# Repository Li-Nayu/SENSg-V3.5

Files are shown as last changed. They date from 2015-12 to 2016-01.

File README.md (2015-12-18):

SENSg-V3.5
==========
<h4>National Science Experiment: SENsg,  Large-scale Internet of Things Sensor Deployment in SUTD, Singapore</h4>

#Overview
V3.5 of SENSg is developed during my exchange period in SUTD, Singapore. Thanks to Professor Wilhelm Erik's kind guidance.

#Change Log
* Add P-channel MOSFET as the power switch for camera. MOSFET is controlled by MCU pin1, which is also the LDR sensor's GPIO pin. 
* With a pull-up resistor, the camera won't on unless the pin1 gives a low voltage. Also the camera's VCC input is changed to MOSFET's source.
* All changes were tested.

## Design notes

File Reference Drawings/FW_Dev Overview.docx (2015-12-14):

# SENSg Firmware Development Overview

# 1. V4

## 1.1. HW

What | Where | Link
Schematics | Google SENSg Drive | https://drive.google.com/drive/folders/0B7DpkhRStnrifm95Z2t1MTVseUd5ZGhOa0FhOWctQkhuNlJZZ3pQanJJbHhZMnU5bmlOZEk
Datasheets | Git SENSgV4 | https://github.com/SUTDMEC/SENSgV4/tree/master/datasheets

## 1.2. SW

What | Where | Link
Firmware Repository | Git SENSgV4 | https://github.com/SUTDMEC/SENSgV4
Development Setup | Git SENSgV4 | https://github.com/SUTDMEC/SENSgV4/wiki
Documentation | Git SENSgV4 | https://github.com/SUTDMEC/SENSgV4/tree/master/documents
Documentation | Google SENSg Drive | https://drive.google.com/drive/folders/0B7DpkhRStnrifmJVV1dtaHV1aF85Tnh1ckhTOUxUanZnam4zbUtBdXp3aHRtV045ZDlzZWM
Test Plans | Google SENSg Drive | https://drive.google.com/drive/folders/0B7DpkhRStnrifnhCbGhJeDdnWGVrSzdkeTBONUJSbk45VVZRVzVYc2ZOX3dZOHlpS0NJYTQ
To Do List | Google SENSg Drive | https://docs.google.com/spreadsheets/d/1tqt-cK1kPYpz1u6wyrGCkvDzCyMbWx9modV9bSj_76Y
Open Issues | Git SENSgV4 | https://github.com/SUTDMEC/SENSgV4/issues

# 2. V3

## 1.3. HW

What | Where | Link
Schematics
Datasheets | Git SenseSing | https://github.com/SUTDMEC/SenseSing/tree/master/V3%20-%20BM-09%20Based/Datasheets

## 1.4. SW

What | Where | Link
Firmware Repository | Git sensg-private | https://github.com/SUTDMEC/sensg-private
Development Setup | Git SenseSing | https://github.com/SUTDMEC/SenseSing/wiki
Development Setup | Google SENSg Drive | https://drive.google.com/drive/folders/0B7DpkhRStnrifmJVV1dtaHV1aF85Tnh1ckhTOUxUanZnam4zbUtBdXp3aHRtV045ZDlzZWM

Firmware Development Overview

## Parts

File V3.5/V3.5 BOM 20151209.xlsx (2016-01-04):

Sub-System | Description & Link | Category | Supplier | DELTA Sourcing | Package / Case | Supplier | Supplier Part # | Units /Piece | Reference on the PCB
Power & Charging | 1800 mAh Li-Po Battery (http://www.alibaba.com/product-detail/3-7v-1800mah-flat-li-ion_701608271.html) | Battery |  | V |  | Data Power |  | 1 |  | USD Conv.
 | 3.3v DC/DC converter (http://www.digikey.sg/product-search/en?x=0&y=0&KeyWords=RT8008-33GB) | IC | Richtek | V | SOT-23 | Digikey | RT8008-33GB-ND | 1 | U3
 | MCP73831T (Charging) (http://sg.element14.com/jsp/search/productdetail.jsp?id=1332158) | IC | Microchip | FIX | SOT-5 | Element14 | 1332158 | 1 | U2
 | MICRO USB (http://sg.element14.com/molex/47346-0001/micro-usb-2-0-type-b-receptacle/dp/1568026) | Connector | MOLEX | V |  | Element14 | 1568026 | 1 | JP1
 | 4.7 uF (http://sg.element14.com/murata/grm155r60j475me47d/cap-mlcc-x5r-4-7uf-6-3v-0402/dp/2426952) | MLCC | Murata | V | 402 | Element14 | 2426952 | 2 | C7,C10
 | 2K OHM (http://sg.element14.com/vishay-draloric/crcw06032k00fkea/product-range-vishay-crcw-series/dp/1469764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) | Resistor | Murata | V | 603 | Element14 | 1469764 | 1 | R1
 | 100 OHM (http://sg.element14.com/yageo-phycomp/rc0603jr-07100rl/resistor-rc21-0603-100r/dp/9233253) | Resistor | Yageo | V | 603 | Element14 | 9233253 | 1 | R3
 | Indicator LED SMT (http://sg.element14.com/kingbright/ka-2810asursk/led-smd-2-8-x-0-8mm-side-view-red/dp/2146470) | LED | Everlight | V | RA_SMD_LED | Element14 | 2146470 | 1 | LED
 | 0.1 uF (0402) (http://sg.element14.com/multicomp/mc0402x104k100ct/cap-mlcc-x5r-100nf-10v-0402/dp/1759380RL) | MLCC | MLCC | V | 402 | Element14 | 1759380RL | 1 | C12
 | 22uf (http://sg.element14.com/tdk/c1608x5r0g226m080aa/ceramic-capacitor-22uf-4v-x5r/dp/2354098) | MLCC |  | V | 603 | Element14 | 2354098 | 2 | C8,C11
 | 100K 1% (http://sg.element14.com/multicomp/mcsr04x1003ftl/resistor-0402-100k-1-anti-sulfur/dp/2073962) | Resistor | Multicomp | V | 402 | Element14 | 2073962 | 1 | R2
 | JST Header 2-way SMT (http://sg.element14.com/jst-japan-solderless-terminals/s2b-ph-sm4-tb-lf-sn/connector-header-smt-r-a-2mm-2way/dp/9492615) | Connector | JST | V |  | Element14 | 9492615 | 1 | BAT
 | Inductor 2.2 uH (http://www.mouser.sg/ProductDetail/Taiyo-Yuden/NR3015T2R2M/?qs=PzICbMaShUc5oMpwvLtSLA%3D%3D) | Inductor | Taiyo Yuden (http://www.mouser.sg/Taiyo-Yuden/) | V | INDUCTOR-NR3015 | Mouser | 963-NR3015T2R2M | 1 | L2
Main PCB components | BM-09 (http://www.usish.com/pdf/EN_flyer.pdf) | MCU+WIFI | USI | FIX |  | EDOM/USI |  | 1 | U1 | USD Conv.
 | 0.1 uF (0402) (http://sg.element14.com/multicomp/mc0402x104k100ct/cap-mlcc-x5r-100nf-10v-0402/dp/1759380RL) | MLCC | MLCC | V | 402 | Element14 | 1759380RL | 4 | C2,C4,c6,C22
 | 10 uF (0402) (http://sg.element14.com/tdk/c1005x5r0j106m050bc/cap-mlcc-x5r-10uf-6-3v-0402/dp/2346872) | MLCC | MLCC | V | 402 | Element14 | 2346872 | 3 | C1,C3,C5
 | 10K OHM 1% (http://sg.element14.com/multicomp/mcsr04x1002ftl/resistor-0402-10k-1-anti-sulfur/dp/2073960) | Resistor | Multicomp | V | 402 | Element14 | 2073960 | 1 | R13
 | SMD Tactice Button (http://sg.element14.com/te-connectivity-alcoswitch/fsm4jsmatr/switch-tactile-spst-50ma-smd-outside/dp/2410652) | Switch | Tyco | V | TACTILE_SWITCH_SMD_LARGE_4 | Element14 | 2410652 | 2 | S1,S2
 | Reset Switch (http://sg.element14.com/webapp/wcs/stores/servlet/ProductDisplay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) | Switch | Multicomp | V | DTSM-3 | Element14 | 9471898 | 2 | S3,S4
 | Switch (http://sg.element14.com/eao/09-10290-01/switch-slide-spdt-co-500ma-thd/dp/674357) | Switch | EAO | V |  | Element14 | 1634623 | 1 | SW
 | 4.7K OHM 1% (http://sg.element14.com/multicomp/mc00625w040214k7/resistor-4k7-0-063w-1-0402/dp/1358060) | Resistor | Multicom | V | 402 | Element14 | 1358060 | 2 | R6,R7
 | RGB LED (http://sg.element14.com/cree/clv1l-fkb-chmmqehbb7673673/led-red-green-blue-plcc-4/dp/2414451?ost=2414451) | LED | CREE | V |  | Element14 | 2414451 | 1 | RGB_LED
 | Chip Antenna (http://www.digikey.sg/product-detail/en/2450AT43B100E/712-1010-2-ND/1560681) | RF Antenna | Johanson | FIX |  | Digikey | 712-1010-2-ND | 1 | ANT1
 | 0.8pF RF CAP (http://www.digikey.sg/product-detail/en/GJM1555C1HR80BB01D/490-6080-2-ND/2593264) | MLCC | Murata | V | 0402_B | Digikey | 490-6080-2-ND | 1 | C9
 | 3.3nH RF IND (http://www.hksunlord.com/Multilayer_Inductor.php?page=7) | Inductor | TBA | V | 0402_B | MFG: Hong Kong SUNLORD Co.,Ltd. | PN: HCI1005F-3N3J | 1 | L1
 | 1K OHM (http://sg.element14.com/multicomp/mc00625w040211k/resistor-1k-0-063w-1-0402-reel/dp/2130354) | Resistor | Multicomp | V | 402 | Element14 | 2130354 | 3 | R9,10,R11
 | 22 ohm (http://sg.element14.com/multicomp/mc00625w0402122r/resistor-22r-0-063w-1-0402/dp/1357998) | Resistor | Multicomp | V | 402 | Element14 | 1357998 | 2 | R4,R5
SD | Micro SD Card Slot (http://sg.element14.com/global-connector-technology/mem2051-00-195-00-a/connector-memory-card-micro-sd/dp/2143377) |  | TBA | V |  |  |  | 1 | U8
 | Micro SD Card 8GB (http://www.alibaba.com/product-detail/8GB-micro-SD-card-Class10-TF_1877618164.html) | IC | TBA | FIX |  | Alibaba |  | 1
IMU | MPU 9150 (http://www.invensense.com/mems/gyro/documents/PS-MPU-9150A-00v4_3.pdf) | MCU |  | FIX |  | Digikey (http://www.digikey.com/product-detail/en/MPU-9150/1428-1009-2-ND/4038013) | 1428-1009-2-ND | 1 | U4
 | 0.1 uF (0402) (http://sg.element14.com/multicomp/mc0402x104k100ct/cap-mlcc-x5r-100nf-10v-0402/dp/1759380RL) | MLCC | Multicomp | V | 402 | Element14 | 1759380RL | 2 | C13,C17
 | 10nF (0.01uF) (http://in.element14.com/tdk/c1005x7r1e103k050bb/capacitor-ceramic-0-01uf-25v-x7r/dp/1844133) | MLCC |  | V | 402 | Element14 | 1844133 | 1 | C18
 | 2.2nF (2200pF) (http://sg.element14.com/murata/grm155r71h222ka01d/cap-mlcc-x7r-2-2nf-50v-0402/dp/1828884) | MLCC | Murata | V | 402 | Element14 | 1828884 | 1 | C14
LDR | LDR (http://sg.element14.com/excelitas-tech/vt90n1/ldr-200kohm-80mw-vt900-series/dp/2568243) | Photoconductive Cell | EXCELITAS TECH | FIX |  | Digikey |  | 1 | KDR
 | 1.2K OHM 1% (http://sg.element14.com/multicomp/mc0063w060311k2/res-thick-film-1k2-1-0-063w-0603/dp/9330500?ost=9330500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) | Resistor | MULTICOMP | V | 603 | Element14 | 9330500 | 1 | R12
 | 2K OHM 1% (http://sg.element14.com/multicomp/mc0063w060312k/res-thick-film-2k-1-0-063w-0603/dp/9330763?ost=9330763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) | Resistor | MULTICOMP | V | 603 | Element14 | 9330763 | 1 | R20
Mic | Mic (http://sg.element14.com/projects-unlimited/aom-4542p-r/microphone-omni-pcb-9-7mm/dp/1193029) | IC | PROJECTS UNLIMITED (http://sg.element14.com/projects-unlimited) | FIX | OFN-24Np | Element14 | 1193029 | 1 | U9
 | OPA344 Opamp (http://sg.element14.com/texas-instruments/opa344na-250/ic-op-amp-1mhz-0-8v-us-sot-23-5/dp/9547550) | IC | TI | FIX | SOT-23-5 | Element14 | 9547550 | 1 | U10
 | 10K OHM 1% (http://sg.element14.com/multicomp/mcsr04x1002ftl/resistor-0402-10k-1-anti-sulfur/dp/2073960) | Resistor | Multicomp | V | 402 | Element14 | 2073960 | 3 | R15,16,R17
 | 1M 1% (http://sg.element14.com/panasonic/erj-2rkf1004x/resistor-thick-film-1mohm-100mw/dp/2284171) | Resistor | Panasonic | V | 402 | Element14 | 2284171 | 1 | R18
 | 12pF (http://sg.element14.com/murata/grm1555c1h120ja01d/cap-mlcc-c0g-np0-12pf-50v-0402/dp/1828875) | MLCC | Murata | V | 402 | Element14 | 1828875 | 1 | C25
 | 2.2 K ohm (http://sg.element14.com/panasonic-electronic-components/erj2rkf2201x/res-thick-film-2k2-100mw-1-0402/dp/2302673) | Resistor | Panasonic | V | 402 | Element14 | 2302673 | 1 | R14
 | 4.7 uF (http://sg.element14.com/murata/grm155r60j475me47d/cap-mlcc-x5r-4-7uf-6-3v-0402/dp/2426952) | MLCC | Murata | V | 402 | Element14 | 2426952 | 1 | C23
 | 1.0 uF (http://sg.element14.com/tdk/c1005x5r0j105k050bb/ceramic-capacitor-1uf-6-3v-x5r/dp/2371907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) | MLCC | C5 | V | 402 | Element14 | 1844105 | 1 | C24
 | 0.1 uF (0402) (http://sg.element14.com/multicomp/mc0402x104k100ct/cap-mlcc-x5r-100nf-10v-0402/dp/1759380RL) | MLCC | Multicomp | V | 402 | Element14 | 1759380RL | 1 | $26.000
Humidity & Temperature | HTU21D (http://sg.element14.com/measurement-specialties/htu21d/humidity-digital-3-rh-dfn-6/dp/2393536?Ntt=HTU21D) | IC | Measurement | FIX |  |  |  | 1 | U5
 | 0.1 uF (0402) (http://sg.element14.com/multicomp/mc0402x104k100ct/cap-mlcc-x5r-100nf-10v-0402/dp/1759380RL) | MLCC | Multicomp | V | 402 | Element14 | 1759380RL | 1 | C15
Barometer | BMP180 (http://www.mouser.sg/ProductDetail/Bosch-Sensortec/BMP180/?qs=sGAEpiMZZMsrChSOYEGTCcbpL13VfRyojs5HQb1tBiU%3d) | IC | Bosch | FIX |  |  | 262-BMP180 | 1 | U7
 | 10uF Tant (http://sg.element14.com/jsp/search/productdetail.jsp?sku=2333009) | CAP | AVX | V | 1206 | Element14 | 2333009 | 1 | C19
 | 0.1 uF (0402) (http://sg.element14.com/multicomp/mc0402x104k100ct/cap-mlcc-x5r-100nf-10v-0402/dp/1759380RL) | MLCC | Multicomp | V | 402 | Element14 | 1759380RL | 2 | C20,C21
IR Temperature | TMP007 (http://www.digikey.sg/product-detail/en/TMP007AIYZFT/296-37914-1-ND/4900960) | IC | TI | FIX |  | Digikey | 296-28819-2-ND | 1 | U6
 | 10K OHM 1% (http://sg.element14.com/jsp/search/productdetail.jsp?sku=1469748RL) | Resistor | Vishay | V | 603 | Element14 | 1469748RL | 1 | R8
 | 0.1 uF (0402) (http://sg.element14.com/multicomp/mc0402x104k100ct/cap-mlcc-x5r-100nf-10v-0402/dp/1759380RL) | MLCC | MLCC | V | 402 | Element14 | 1759380RL | 1 | C16
Buzzer | ID 1740 Buzzer (http://www.adafruit.com/product/1740) | Buzzer | Adafruit | V |  | Adafruit | 1740 | 1 | BUZZ | USD Conv.
Camera | C1098 (http://www.comedia.com.hk/) | Camera | 康大 | V |  | COMedia |  | 1 | CAM | JPEG serial camera. Minimum VGA quality.
 | P-CHANNEL MOSFET (http://sg.element14.com/fairchild-semiconductor/nds356ap/mosfet-p-sot-23/dp/9846409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) | MOSFET | Fairchild Semiconductor | V | SOT-23 | Element14 | 9846409 | 1 | Q1
 | Header (http://sg.element14.com/molex/22-03-2041/header-square-pin-0-1-4way/dp/9731091) | Connector | Molex | V |  | element14 | 9731091 | 1
Additional components | Case (thermoplastic injection molded) |  |  |  |  |  |  | 1
Programming Board | JTAG header (http://sg.element14.com/fci/20021111-00008t4lf/header-vert-1-27mm-tht-8way/dp/1865284) | Connector | FCI | v |  | Element14 | 1865284 | 1 | Jtag

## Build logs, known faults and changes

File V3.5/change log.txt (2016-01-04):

Schematic:
1.Changed to Micro USB B.lbr
2.Changed the position of LDR and R12£¬add pull-up resistor R20.

pin1 voltage: [R12 & R20 are tested]
condition                       value
total darkness               around 3.0V
normal condition          2.5V
with phone's flashlight around  2.0V
MOSFET S output
in any condition above 
<=0.3V

3.Add P-channel Mosfet
4.Changed Camera's 3.3V port, named it MOSFET_CONTROL

ERC & DRC check

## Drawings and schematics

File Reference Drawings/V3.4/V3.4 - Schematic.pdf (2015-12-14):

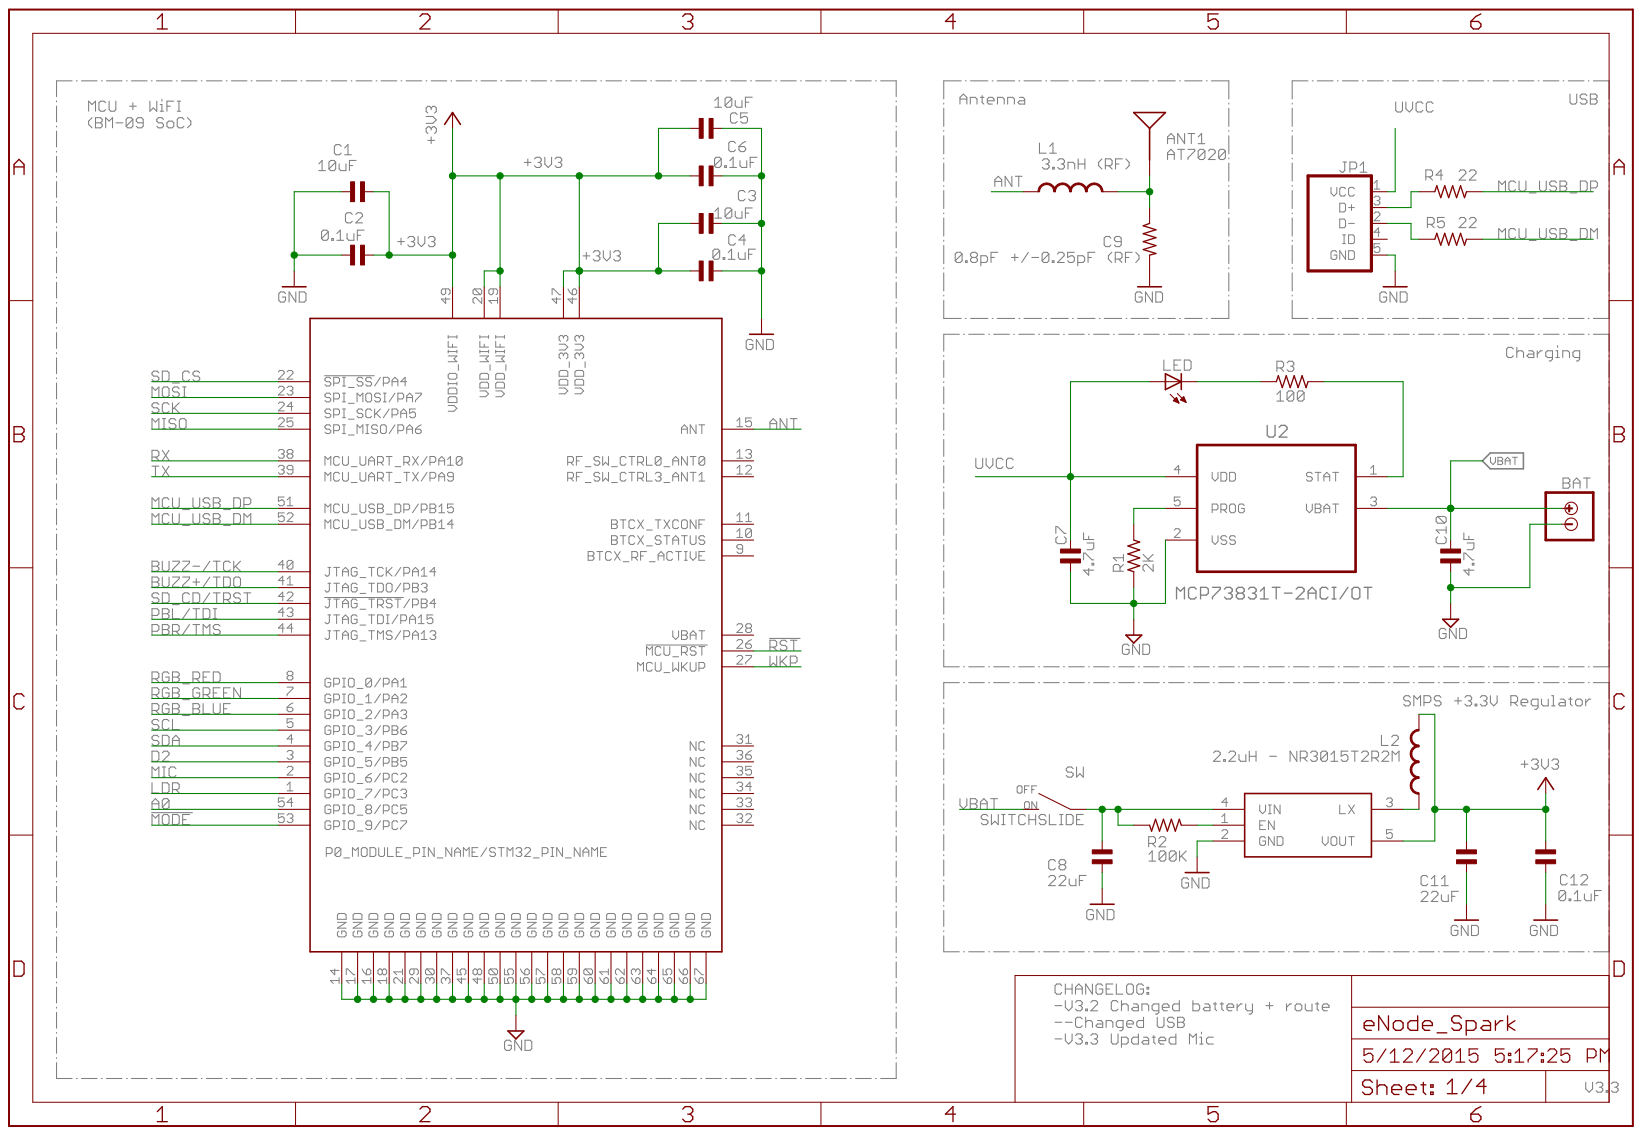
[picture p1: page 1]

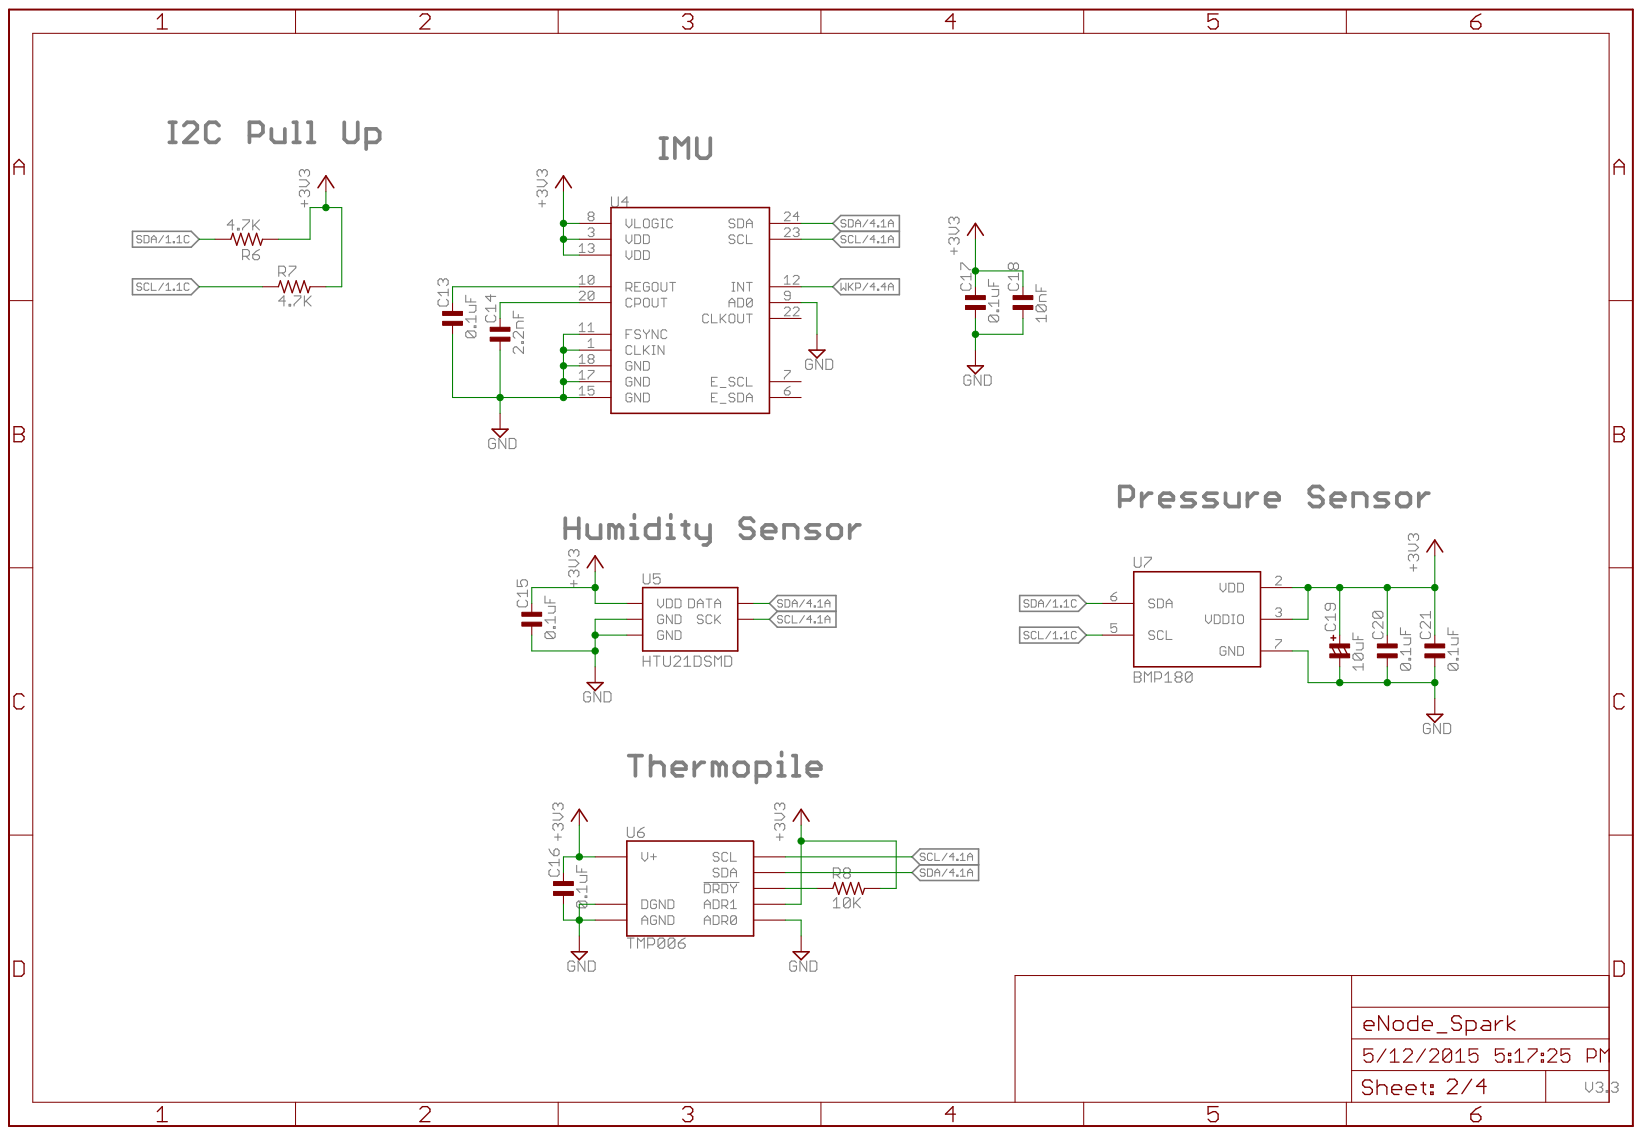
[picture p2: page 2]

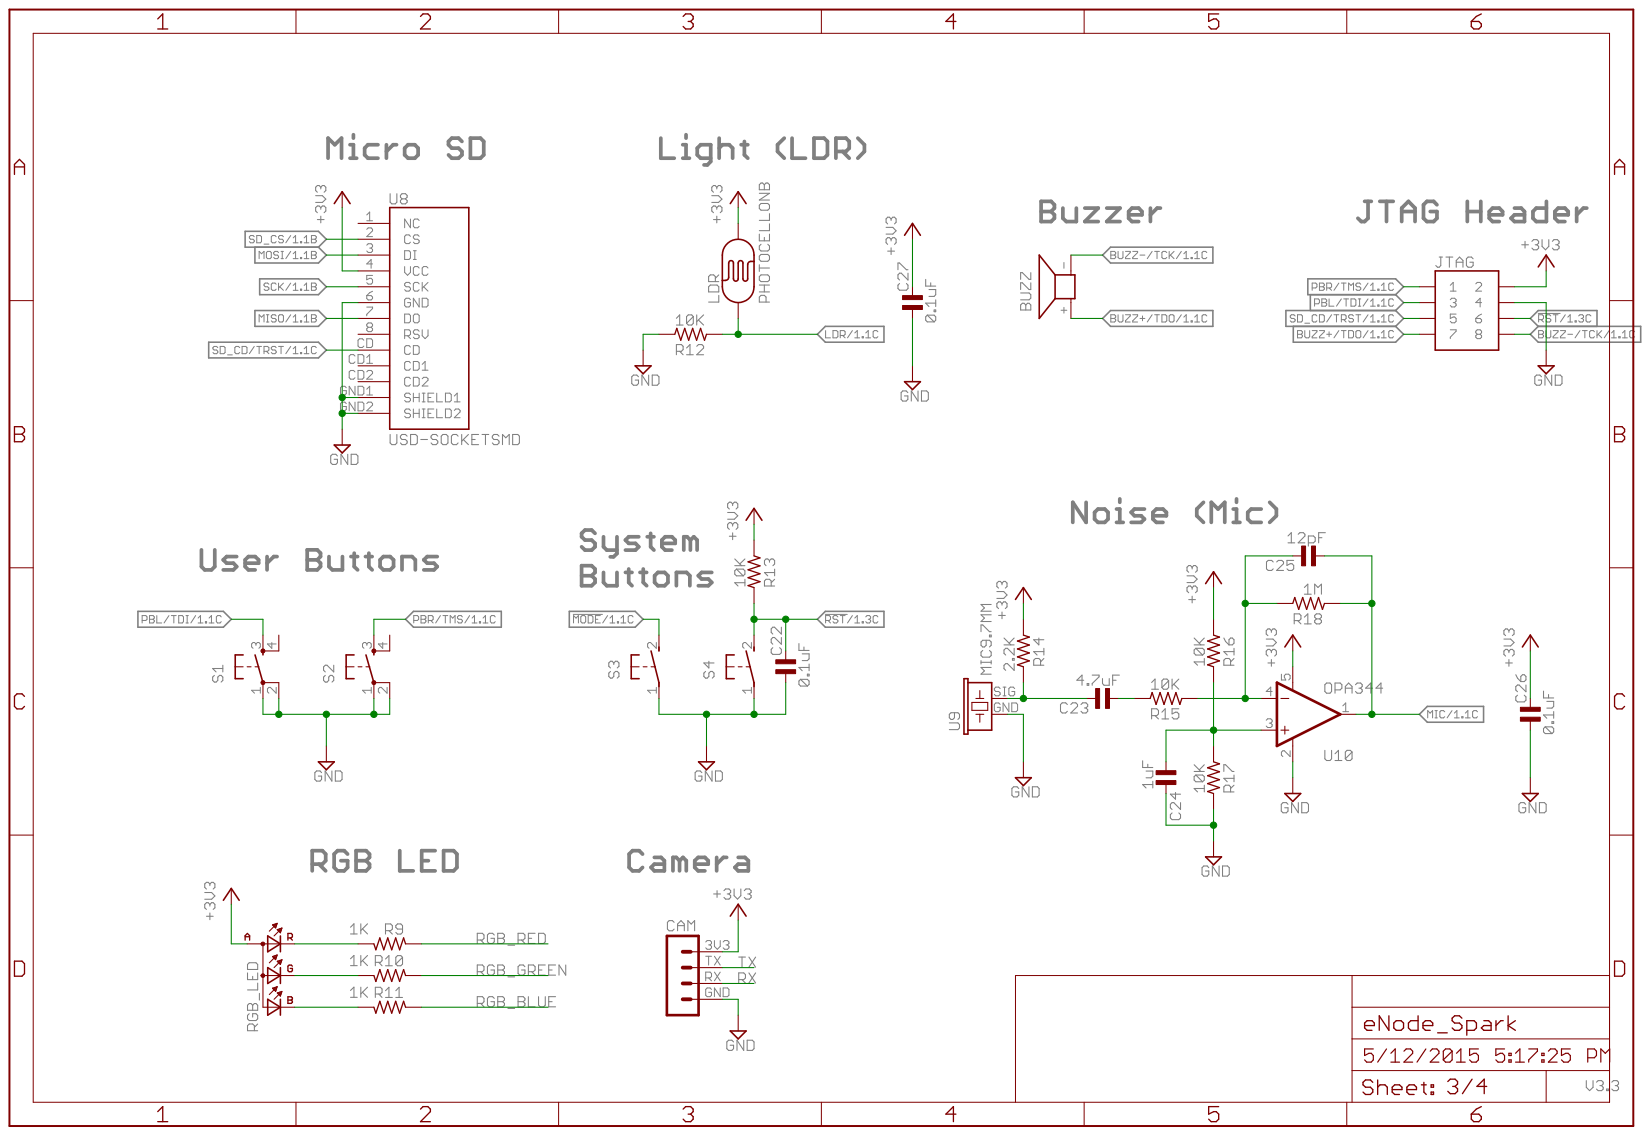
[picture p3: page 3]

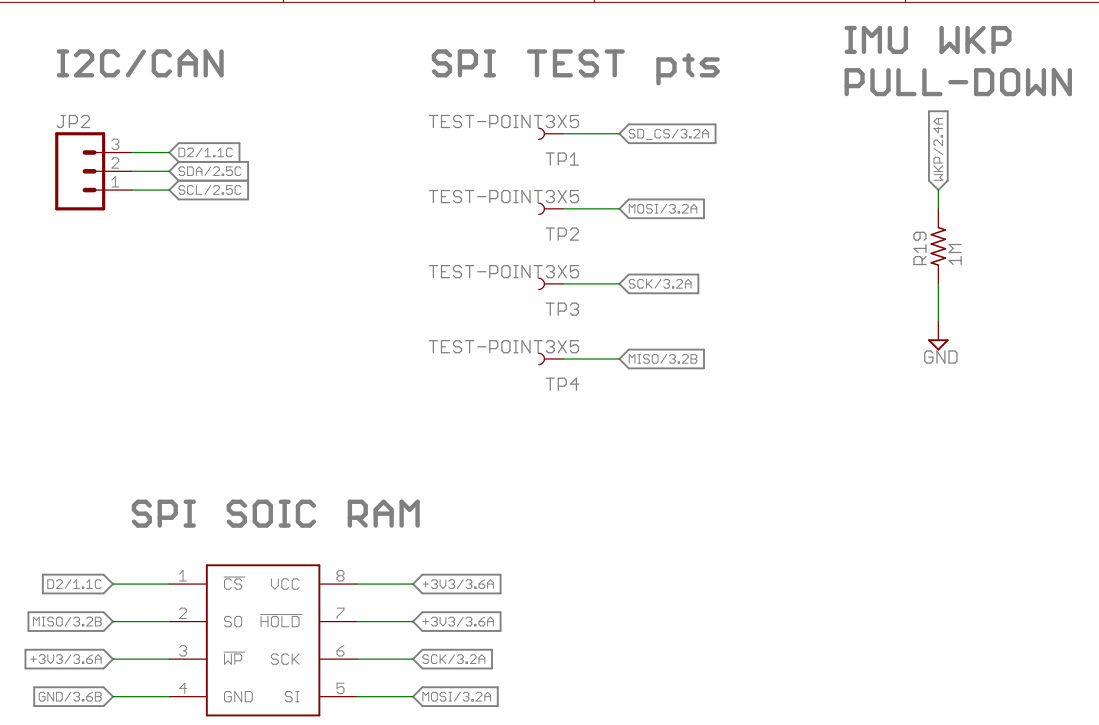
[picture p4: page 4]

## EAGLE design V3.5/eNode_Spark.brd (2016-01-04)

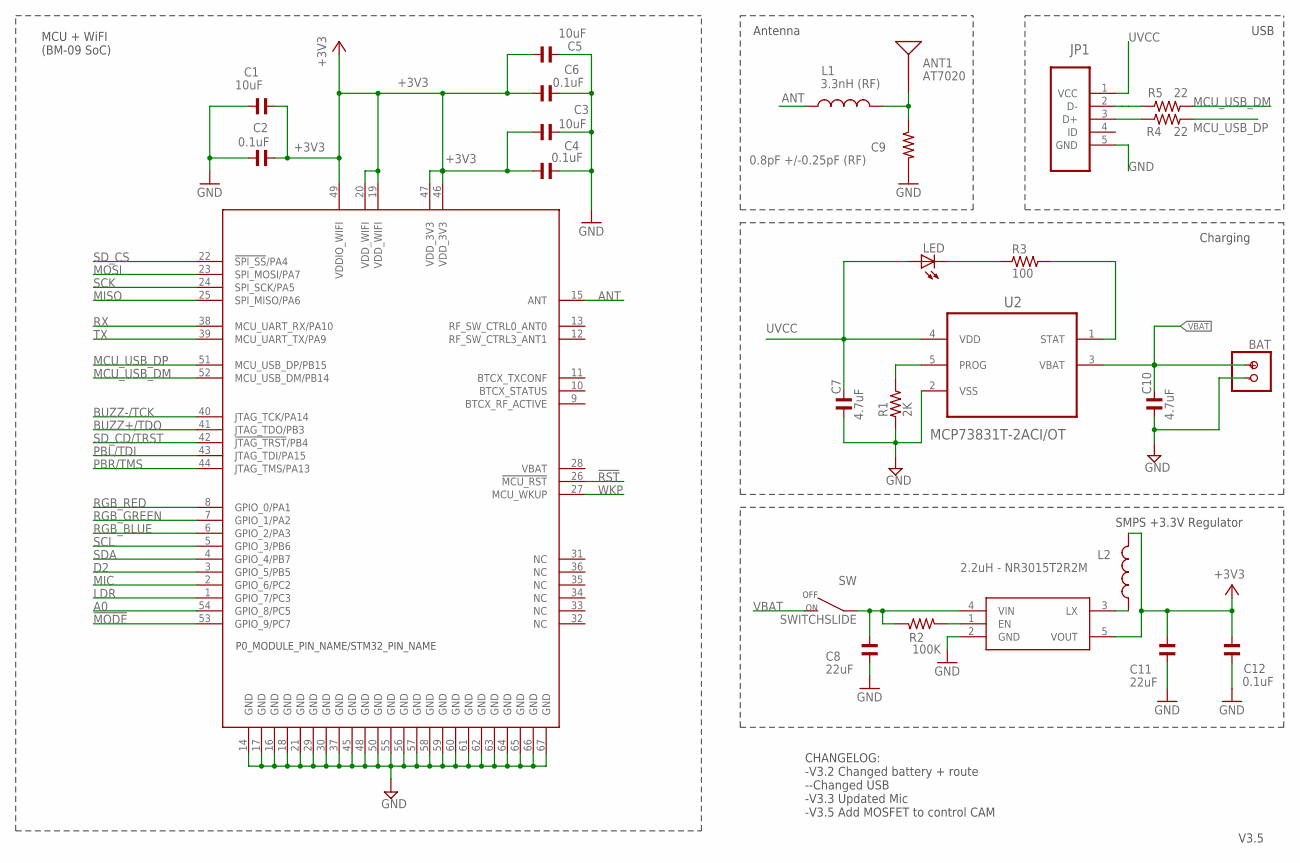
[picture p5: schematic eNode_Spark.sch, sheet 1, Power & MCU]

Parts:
ANT1: AT7020
BAT: BATTERYSMT; JST-2-SMD
C1, C3, C5: 10uF; C0402
C2, C4, C6, C12: 0.1uF; C0402
C7, C10: 4.7uF; C0402
C8, C11: 22uF; C0603
C9: 0.8pF +/-0.25pF (RF); R0402_B
JP1: 47346-0001; MOLEX_47346-0001
L1: 3.3nH (RF); L0402_B
L2: 2.2uH - NR3015T2R2M; INDUCTOR-NR3015
LED: LED; SMARTLED-TTW
R1: 2K; R0603
R2: 100K; R0402
R3: 100; R0603
R4, R5: 22; R0402
SW: SWITCHSLIDE; CHANGE_OVER_SLIDE
U1: WM-N-BM-09
U2: MCP73831T-2ACI/OT; SOT95P280X145-5N
U3: R8008-33; SOT23-5

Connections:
!MODE: U1.53 (GPIO_9/PC7); also elsewhere on the board
!RST: U1.26 (!MCU_RST); also elsewhere on the board
+3V3: C1.2, C2.2, C3.1, C4.2, C5.1, C6.2, C11.1, C12.1, L2.2, U1.19 (VDD_WIFI), U1.20 (VDD_WIFI), U1.46 (VDD_3V3), U1.47 (VDD_3V3), U1.49 (VDDIO_WIFI), U3.5 (VOUT); also elsewhere on the board
A0: U1.54 (GPIO_8/PC5)
ANT: L1.1, U1.15 (ANT)
BUZZ+/TDO: U1.41 (JTAG_TDO/PB3); also elsewhere on the board
BUZZ-/TCK: U1.40 (JTAG_TCK/PA14); also elsewhere on the board
D2: U1.3 (GPIO_5/PB5); also elsewhere on the board
ENABLE: R2.1, U3.1 (EN)
GND: BAT.-, C1.1, C2.1, C3.2, C4.1, C5.2, C6.1, C7.1, C8.2, C9.2, C10.1, C11.2, C12.2, JP1.5 (GND), R1.1, U1.14 (GND), U1.16 (GND), U1.17 (GND), U1.18 (GND), U1.21 (GND), U1.29 (GND), U1.30 (GND), U1.37 (GND), U1.45 (GND), U1.48 (GND), U1.50 (GND), U1.55 (GND), U1.56 (GND), U1.57 (GND), U1.58 (GND), U1.59 (GND), U1.60 (GND), U1.61 (GND), U1.62 (GND), U1.63 (GND), U1.64 (GND), U1.65 (GND), U1.66 (GND), U1.67 (GND), U2.2 (VSS), U3.2 (GND); also elsewhere on the board
LDR: U1.1 (GPIO_7/PC3); also elsewhere on the board
MCU_USB_DM: R5.1, U1.52 (MCU_USB_DM/PB14)
MCU_USB_DP: R4.1, U1.51 (MCU_USB_DP/PB15)
MIC: U1.2 (GPIO_6/PC2); also elsewhere on the board
MISO: U1.25 (SPI_MISO/PA6); also elsewhere on the board
MOSI: U1.23 (SPI_MOSI/PA7); also elsewhere on the board
unnamed: ANT1.1, C9.1, L1.2
unnamed: C8.1, R2.2, SW.1, U3.4 (VIN)
unnamed: L2.1, U3.3 (LX)
unnamed: R1.2, U2.5 (PROG)
unnamed: LED.C@1 (C), R3.1
unnamed: R3.2, U2.1 (STAT)
unnamed: JP1.3 (D+), R4.2
unnamed: JP1.2 (D-), R5.2
PBL/TDI: U1.43 (JTAG_TDI/PA15); also elsewhere on the board
PBR/TMS: U1.44 (JTAG_TMS/PA13); also elsewhere on the board
RGB_BLUE: U1.6 (GPIO_2/PA3); also elsewhere on the board
RGB_GREEN: U1.7 (GPIO_1/PA2); also elsewhere on the board
RGB_RED: U1.8 (GPIO_0/PA1); also elsewhere on the board
RX: U1.38 (MCU_UART_RX/PA10); also elsewhere on the board
SCK: U1.24 (SPI_SCK/PA5); also elsewhere on the board
SCL: U1.5 (GPIO_3/PB6); also elsewhere on the board
SDA: U1.4 (GPIO_4/PB7); also elsewhere on the board
SD_CD/TRST: U1.42 (!JTAG_TRST!/PB4); also elsewhere on the board
SD_CS: U1.22 (!SPI_SS!/PA4); also elsewhere on the board
TX: U1.39 (MCU_UART_TX/PA9); also elsewhere on the board
UVCC: C7.2, JP1.1 (VCC), LED.A@1 (A), U2.4 (VDD)
VBAT: BAT.+, C10.2, SW.2, U2.3 (VBAT)
WKP: U1.27 (MCU_WKUP); also elsewhere on the board

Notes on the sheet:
V3.5
CHANGELOG: -V3.2 Changed battery + route --Changed USB -V3.3 Updated Mic -V3.5 Add MOSFET to control CAM
USB
MCU + WiFI (BM-09 SoC)
Charging
Antenna
SMPS +3.3V Regulator

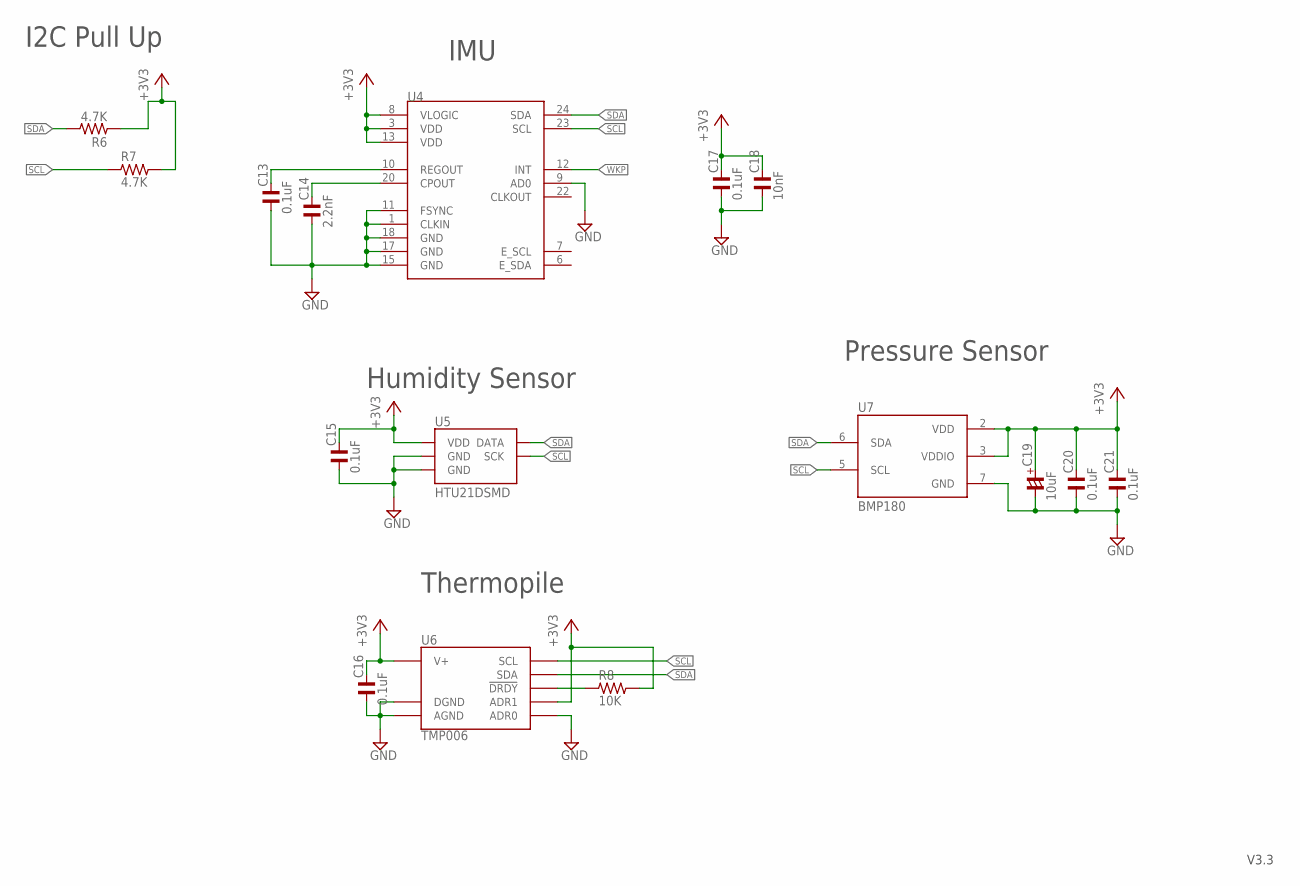
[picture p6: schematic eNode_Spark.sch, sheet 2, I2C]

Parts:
C13, C15, C16, C17, C20, C21: 0.1uF; C0402
C14: 2.2nF; C0402
C18: 10nF; C0402
C19: 10uF; C1206/T
R6, R7: 4.7K; R0402
R8: 10K; R0603
U4: MPU-9150QFN-24-NP; QFN-24-NP
U5: HTU21DSMD; HTU21D
U6: TMP006; BGA8DS
U7: BMP180

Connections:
+3V3: C15.2, C16.2, C17.2, C18.2, C19.+, C20.2, C21.2, R6.1, R7.2, R8.2, U4.3 (VDD), U4.8 (VLOGIC), U4.13 (VDD), U5.VDD, U6.A3 (V+), U6.B1 (ADR1), U7.2 (VDD), U7.3 (VDDIO); also elsewhere on the board
GND: C13.1, C14.1, C15.1, C16.1, C17.1, C18.1, C19.-, C20.1, C21.1, U4.1 (CLKIN), U4.9 (AD0), U4.11 (FSYNC), U4.15 (GND), U4.17 (GND), U4.18 (GND), U5.7 (GND), U5.GND, U6.A1 (DGND), U6.A2 (AGND), U6.C1 (ADR0), U7.7 (GND); also elsewhere on the board
unnamed: C14.2, U4.20 (CPOUT)
unnamed: C13.2, U4.10 (REGOUT)
unnamed: R8.1, U6.C2 (!DRDY)
SCL: R7.1, U4.23 (SCL), U5.SCK, U6.B3 (SCL), U7.5 (SCL); also elsewhere on the board
SDA: R6.2, U4.24 (SDA), U5.DATA, U6.C3 (SDA), U7.6 (SDA); also elsewhere on the board
WKP: U4.12 (INT); also elsewhere on the board

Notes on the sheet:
IMU
Humidity Sensor
Pressure Sensor
Thermopile
I2C Pull Up

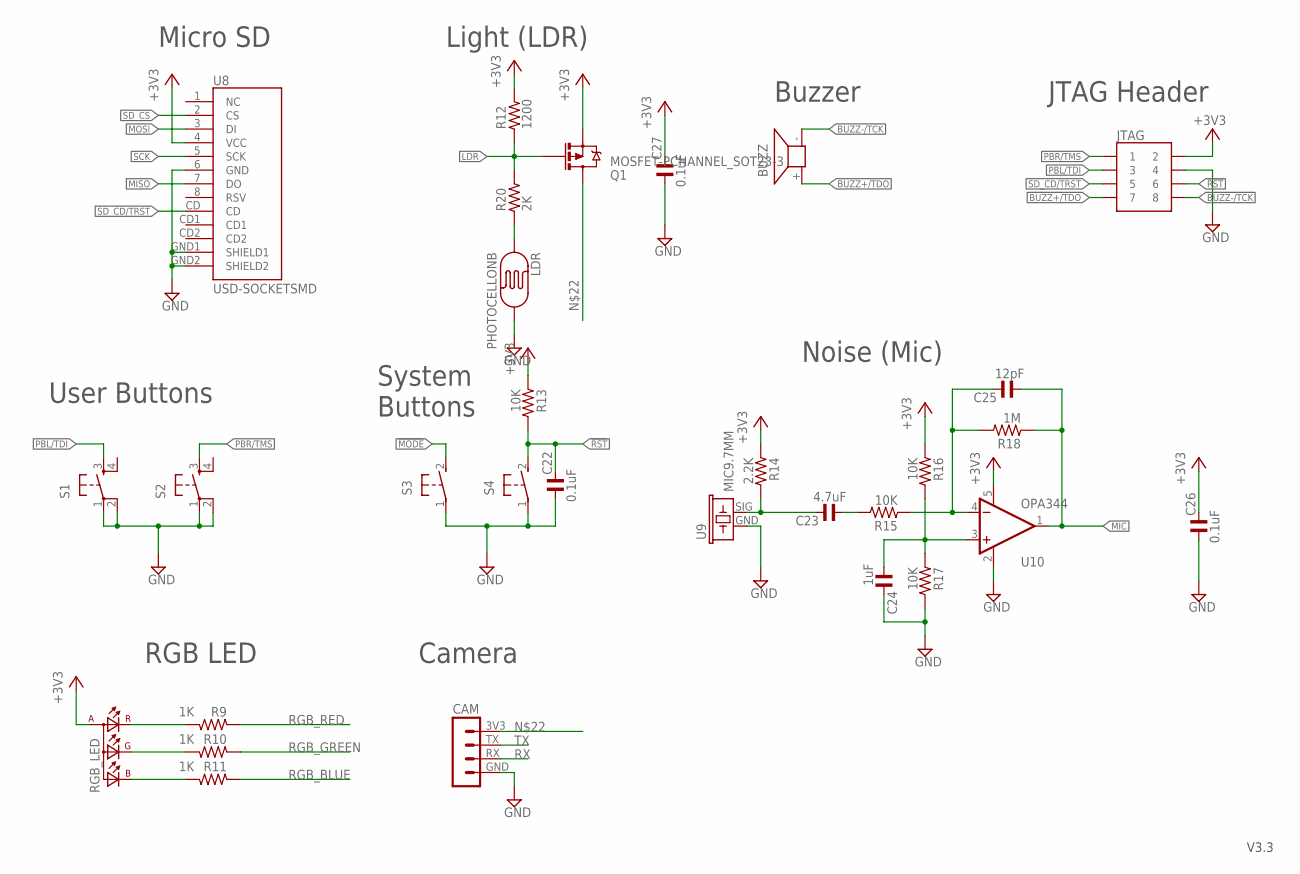
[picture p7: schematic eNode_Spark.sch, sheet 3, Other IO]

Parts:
BUZZ: BUZZER; OFFBOARD_NOSIGN
C22, C26, C27: 0.1uF; C0402
C23: 4.7uF; C0402
C24: 1uF; C0402
C25: 12pF; C0402
CAM: MA04-1
JTAG: JTAG_CONNECTOR; JTAG_DIP
LDR: PHOTOCELLONB; ON_BOARD
Q1: MOSFET-PCHANNEL_SOT23-3; SOT23-3
R9, R10, R11: 1K; R0402
R12: 1200; R0603
R13, R15, R16, R17: 10K; R0402
R14: 2.2K; R0402
R18: 1M; R0402
R20: 2K; R0603
RGB_LED: TOPLED-3PLCC; P-LCC-4-3
S1, S2: TAC_SWITCH_4SMD; TACTILE_SWITCH_SMD_LARGE_4
S3: MODE; DTSM-3
S4: RESET; DTSM-3
U8: USD-SOCKETSMD; MICRO-SD-SOCKET-PP
U9: MIC9.7MM; MIC-9.7MM
U10: OPA344; SOT23-5

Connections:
!MODE: S3.2; also elsewhere on the board
!RST: C22.2, JTAG.6, R13.2, S4.2; also elsewhere on the board
+3V3: C26.2, C27.2, JTAG.2, Q1.2 (S), R12.2, R13.1, R14.1, R16.1, RGB_LED.A (A2), U8.4 (VCC), U10.5 (V+); also elsewhere on the board
BUZZ+/TDO: BUZZ.+, JTAG.7; also elsewhere on the board
BUZZ-/TCK: BUZZ.-, JTAG.8; also elsewhere on the board
GND: C22.1, C24.2, C26.1, C27.1, CAM.GND, JTAG.4, LDR.2, R17.2, S1.1, S1.2, S2.1, S2.2, S3.1, S4.1, U8.6 (GND), U8.GND1 (SHIELD1), U8.GND2 (SHIELD2), U9.GND, U10.2 (V-); also elsewhere on the board
LDR: Q1.1 (G), R12.1, R20.2; also elsewhere on the board
MIC: C25.1, R18.1, U10.1 (OUT); also elsewhere on the board
MISO: U8.7 (DO); also elsewhere on the board
MOSI: U8.3 (DI); also elsewhere on the board
unnamed: C23.1, R15.2
unnamed: C25.2, R15.1, R18.2, U10.4 (-IN)
unnamed: C24.1, R16.2, R17.1, U10.3 (+IN)
unnamed: C23.2, R14.2, U9.SIG
unnamed: LDR.1, R20.1
unnamed: CAM.3V3, Q1.3 (D)
unnamed: R10.1, RGB_LED.G (CGREEN)
unnamed: R11.1, RGB_LED.B (CBLUE)
unnamed: R9.1, RGB_LED.R (CRED)
PBL/TDI: JTAG.3, S1.3; also elsewhere on the board
PBR/TMS: JTAG.1, S2.3; also elsewhere on the board
RGB_BLUE: R11.2; also elsewhere on the board
RGB_GREEN: R10.2; also elsewhere on the board
RGB_RED: R9.2; also elsewhere on the board
RX: CAM.RX; also elsewhere on the board
SCK: U8.5 (SCK); also elsewhere on the board
SD_CD/TRST: JTAG.5, U8.CD; also elsewhere on the board
SD_CS: U8.2 (CS); also elsewhere on the board
TX: CAM.TX; also elsewhere on the board

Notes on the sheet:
Micro SD
User Buttons
Light (LDR)
Buzzer
Noise (Mic)
RGB LED
Camera
System Buttons
JTAG Header

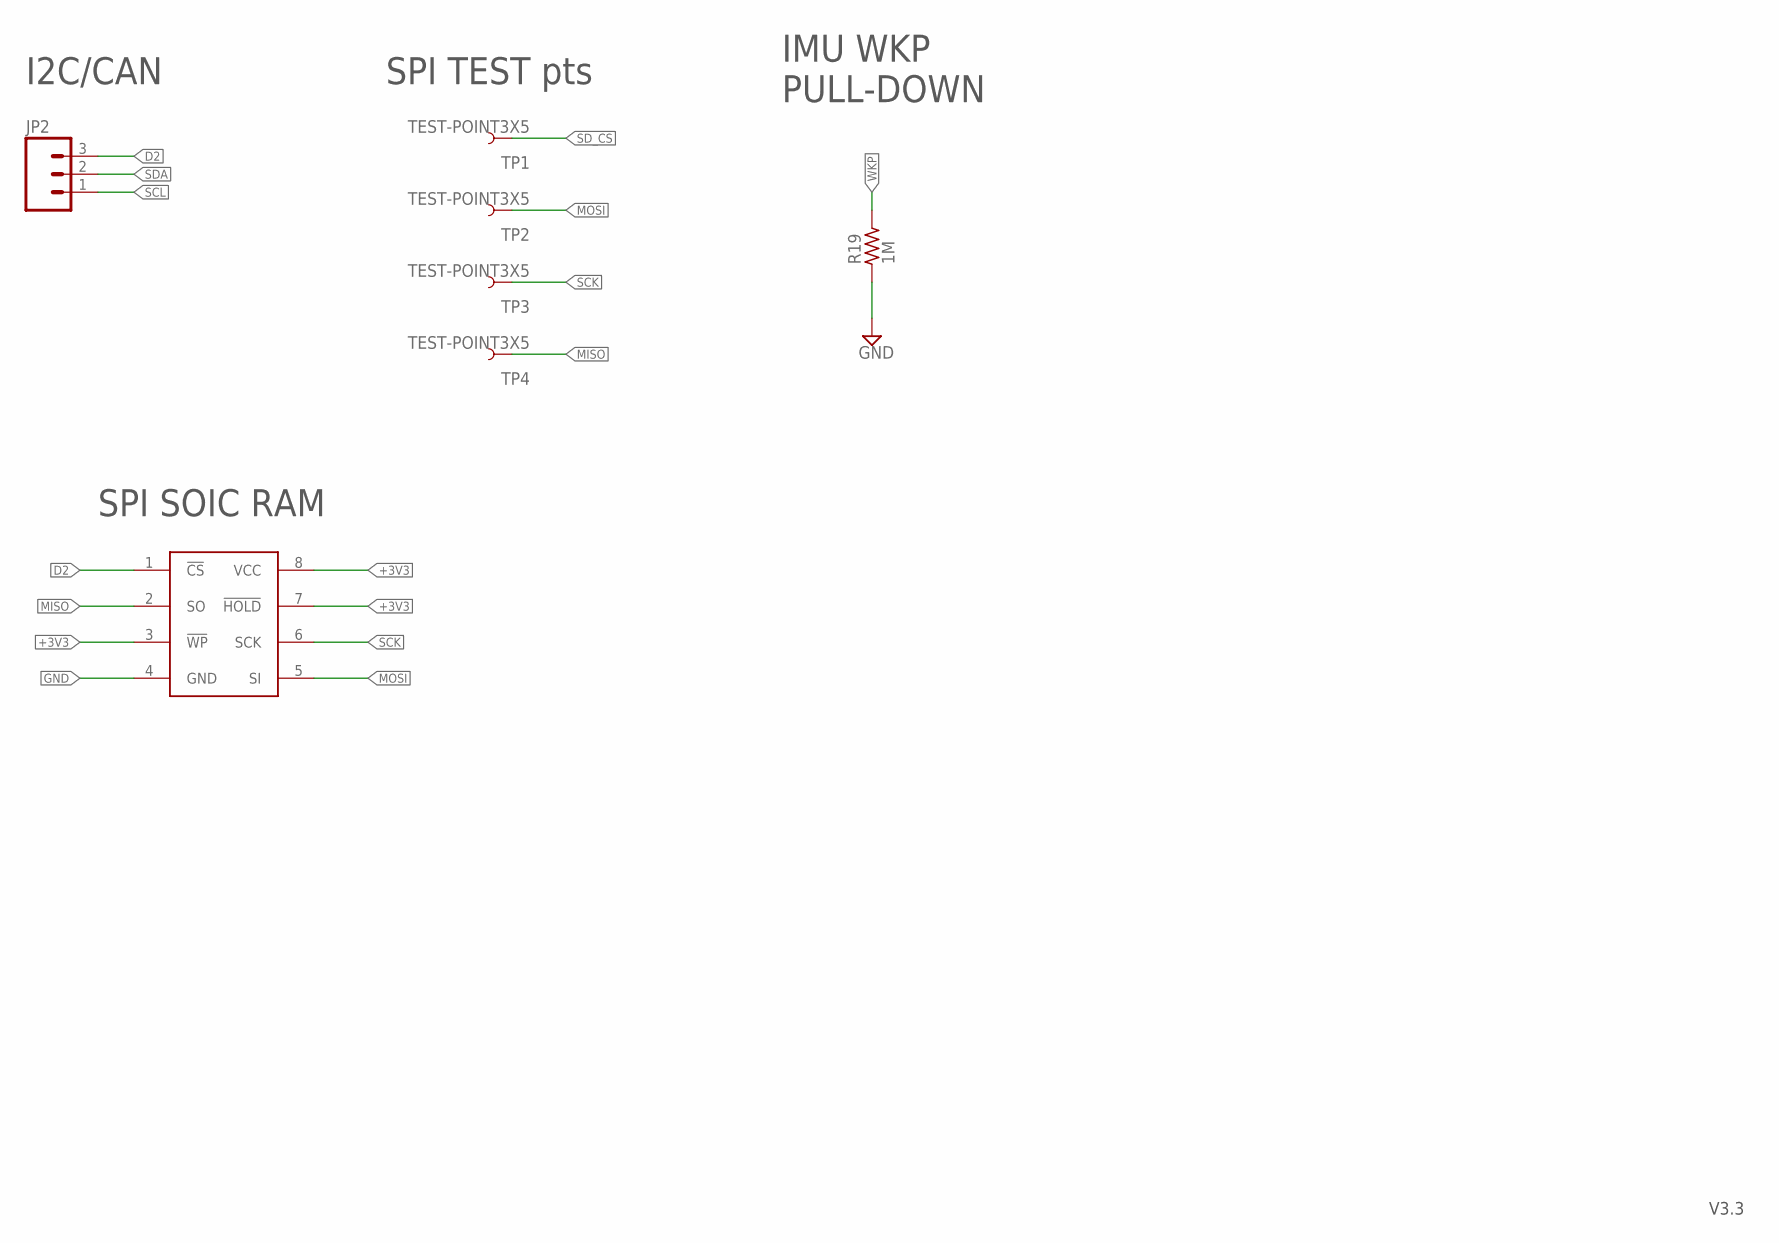
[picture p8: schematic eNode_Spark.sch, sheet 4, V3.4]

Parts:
JP2: M03PTH; 1X03
R19: 1M; R0402
TP1, TP2, TP3, TP4: TEST-POINT3X5; PAD.03X.05
U11: FRAM; SO08

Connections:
+3V3: U11.3 (!WP), U11.7 (!HOLD), U11.8 (VCC); also elsewhere on the board
D2: JP2.3, U11.1 (!CS); also elsewhere on the board
GND: R19.1, U11.4 (GND); also elsewhere on the board
MISO: TP4.P$1, U11.2 (SO); also elsewhere on the board
MOSI: TP2.P$1, U11.5 (SI); also elsewhere on the board
SCK: TP3.P$1, U11.6 (SCK); also elsewhere on the board
SCL: JP2.1; also elsewhere on the board
SDA: JP2.2; also elsewhere on the board
SD_CS: TP1.P$1; also elsewhere on the board
WKP: R19.2; also elsewhere on the board

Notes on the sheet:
I2C/CAN
SPI TEST pts
SPI SOIC RAM
IMU WKP PULL-DOWN

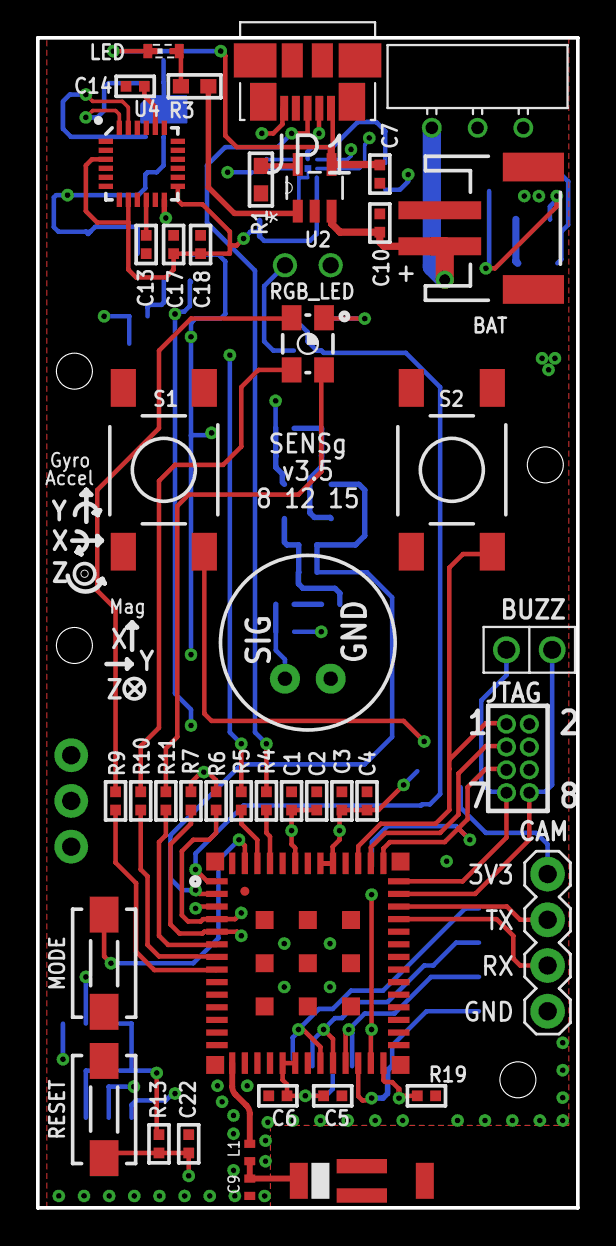
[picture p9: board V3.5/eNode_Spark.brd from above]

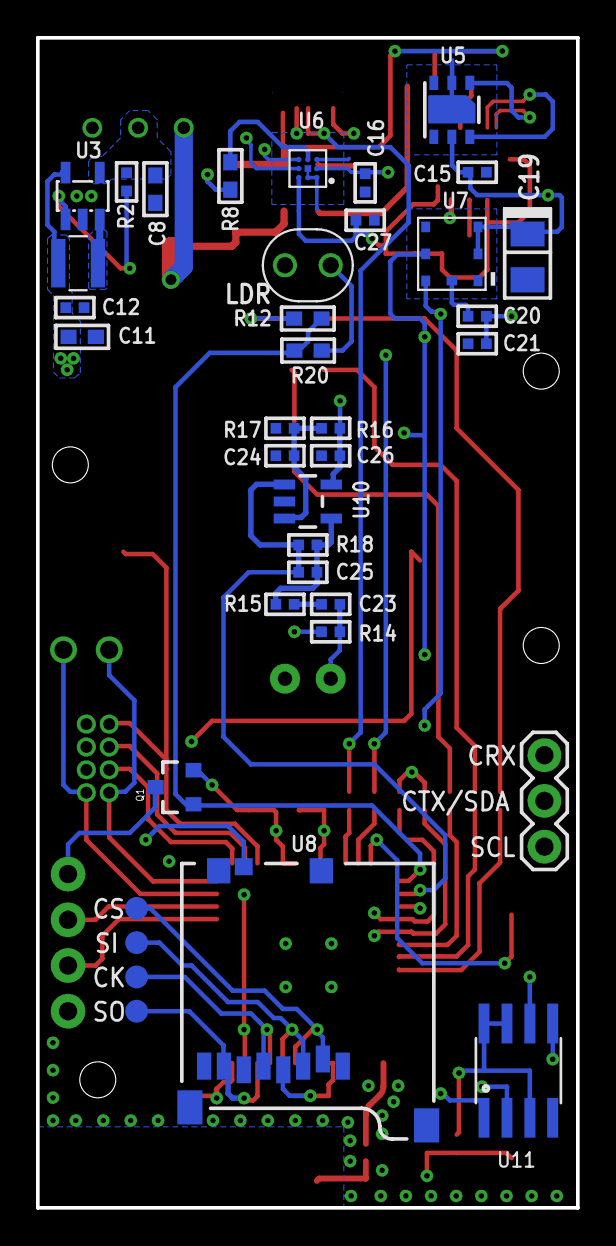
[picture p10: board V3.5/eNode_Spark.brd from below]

Board: 4 copper layers, 30.0 x 65.0 mm, 80 parts (37 on the bottom side), 50 nets.

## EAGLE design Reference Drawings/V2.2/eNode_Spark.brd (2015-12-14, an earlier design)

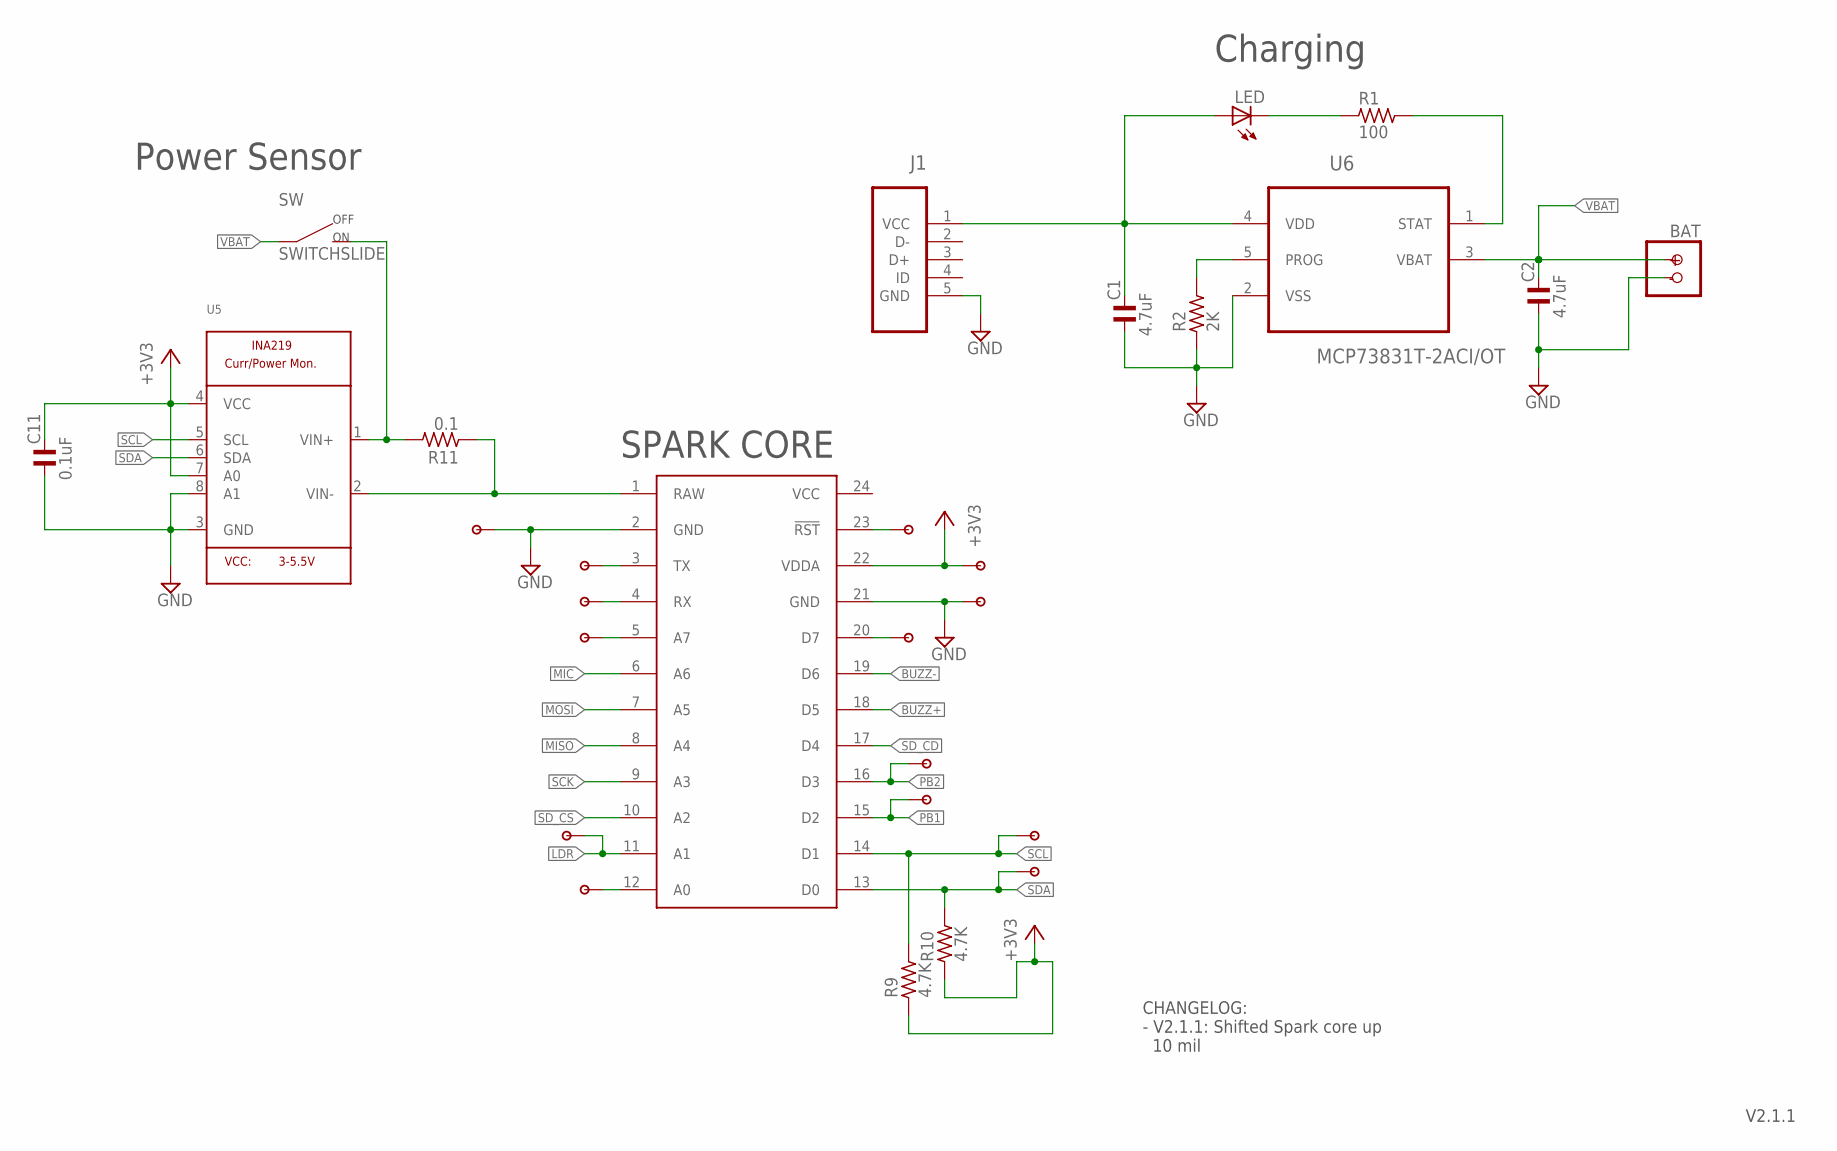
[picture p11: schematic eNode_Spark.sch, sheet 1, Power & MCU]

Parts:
BAT: BATTERYSMT; JST-2-SMD
C1, C2: 4.7uF; C0402
C11: 0.1uF; C0402
J1: 47346-0001; MOLEX_47346-0001
LED: LED; RA_SMD_LED
R1: 100; R0603
R2: 2K; R0603
R9, R10: 4.7K; R0603
R11: 0.1; R2512
SPARK: SPARK_CORECORE; SPARK_CORE
SW: SWITCHSLIDE; CHANGE_OVER_SLIDE
U5: INA219; SOT23-8
U6: MCP73831T-2ACI/OT; SOT95P280X145-5N
U$1, U$2, U$6, U$7, U$8, U$9, U$10, U$11, U$12, U$13, U$14, U$15, U$16, U$17: 1PIN

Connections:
+3V3: C11.2, R9.1, R10.1, SPARK.22 (VDDA), U5.4 (VCC), U5.7 (A0), U$6.P$1; also elsewhere on the board
BUZZ+: SPARK.18 (D5); also elsewhere on the board
BUZZ-: SPARK.19 (D6); also elsewhere on the board
GND: BAT.-, C1.1, C2.1, C11.1, J1.5 (GND), R2.1, SPARK.2 (GND), SPARK.21 (GND), U5.3 (GND), U5.8 (A1), U6.2 (VSS), U$11.P$1, U$17.P$1; also elsewhere on the board
LDR: SPARK.11 (A1), U$16.P$1; also elsewhere on the board
MIC: SPARK.6 (A6); also elsewhere on the board
MISO: SPARK.8 (A4); also elsewhere on the board
MOSI: SPARK.7 (A5); also elsewhere on the board
unnamed: C1.2, J1.1 (VCC), LED.A, U6.4 (VDD)
unnamed: R11.1, SPARK.1 (RAW), U5.2 (VIN-)
unnamed: R2.2, U6.5 (PROG)
unnamed: LED.C, R1.1
unnamed: R1.2, U6.1 (STAT)
unnamed: SPARK.5 (A7), U$2.P$1
unnamed: R11.2, SW.2, U5.1 (VIN+)
unnamed: SPARK.20 (D7), U$10.P$1
unnamed: SPARK.12 (A0), U$1.P$1
unnamed: SPARK.3 (TX), U$12.P$1
unnamed: SPARK.4 (RX), U$13.P$1
unnamed: SPARK.23 (!RST), U$14.P$1
PB1: SPARK.15 (D2), U$9.P$1; also elsewhere on the board
PB2: SPARK.16 (D3), U$15.P$1; also elsewhere on the board
SCK: SPARK.9 (A3); also elsewhere on the board
SCL: R9.2, SPARK.14 (D1), U5.5 (SCL), U$7.P$1; also elsewhere on the board
SDA: R10.2, SPARK.13 (D0), U5.6 (SDA), U$8.P$1; also elsewhere on the board
SD_CD: SPARK.17 (D4); also elsewhere on the board
SD_CS: SPARK.10 (A2); also elsewhere on the board
VBAT: BAT.+, C2.2, SW.1, U6.3 (VBAT)
VCC: SPARK.24 (VCC)

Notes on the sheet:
SPARK CORE
Charging
Power Sensor
V2.1.1
CHANGELOG: - V2.1.1: Shifted Spark core up 10 mil

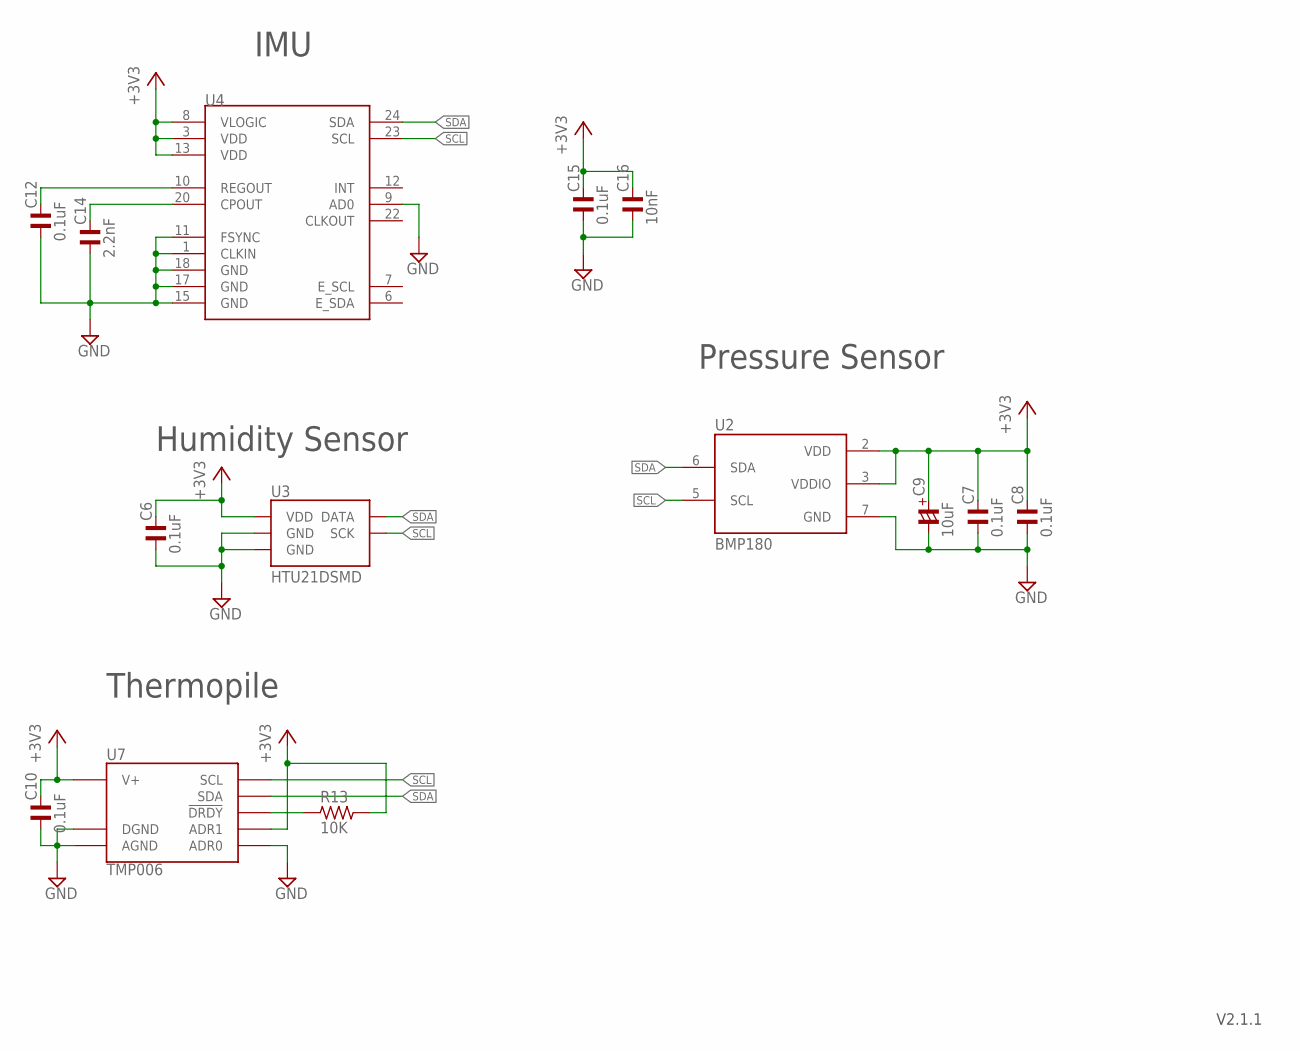
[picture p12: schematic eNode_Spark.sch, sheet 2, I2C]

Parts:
C6, C7, C8, C10, C12, C15: 0.1uF; C0402
C9: 10uF; C1206/T
C14: 2.2nF; C0402
C16: 10nF; C0402
R13: 10K; R0603
U2: BMP180
U3: HTU21DSMD; HTU21D
U4: MPU-9150QFN-24-NP; QFN-24-NP
U7: TMP006; BGA8DS

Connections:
+3V3: C6.2, C7.2, C8.2, C9.+, C10.2, C15.2, C16.2, R13.2, U2.2 (VDD), U2.3 (VDDIO), U3.VDD, U4.3 (VDD), U4.8 (VLOGIC), U4.13 (VDD), U7.A3 (V+), U7.B1 (ADR1); also elsewhere on the board
GND: C6.1, C7.1, C8.1, C9.-, C10.1, C12.1, C14.1, C15.1, C16.1, U2.7 (GND), U3.7 (GND), U3.GND, U4.1 (CLKIN), U4.9 (AD0), U4.11 (FSYNC), U4.15 (GND), U4.17 (GND), U4.18 (GND), U7.A1 (DGND), U7.A2 (AGND), U7.C1 (ADR0); also elsewhere on the board
unnamed: C14.2, U4.20 (CPOUT)
unnamed: R13.1, U7.C2 (!DRDY)
unnamed: C12.2, U4.10 (REGOUT)
SCL: U2.5 (SCL), U3.SCK, U4.23 (SCL), U7.B3 (SCL); also elsewhere on the board
SDA: U2.6 (SDA), U3.DATA, U4.24 (SDA), U7.C3 (SDA); also elsewhere on the board

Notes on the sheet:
IMU
Humidity Sensor
Pressure Sensor
Thermopile
V2.1.1

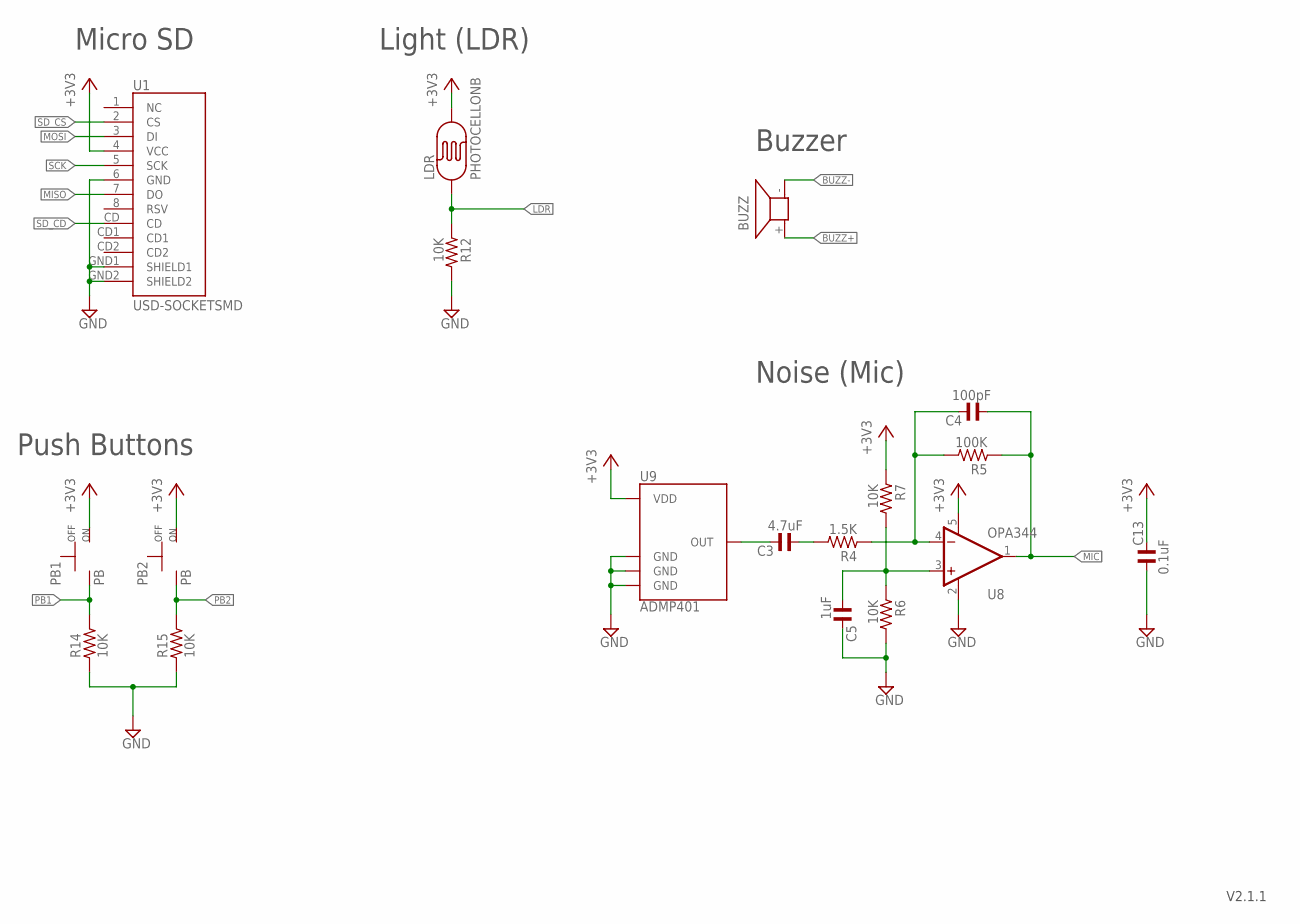
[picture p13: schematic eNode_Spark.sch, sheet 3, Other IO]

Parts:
BUZZ: BUZZER; OFFBOARD_NOSIGN
C3: 4.7uF; C0402
C4: 100pF; C0402
C5: 1uF; C0402
C13: 0.1uF; C0402
LDR: PHOTOCELLONB; ON_BOARD
PB1, PB2: PB
R4: 1.5K; R0402
R5: 100K; R0402
R6, R7: 10K; R0402
R12, R14, R15: 10K; R0603
U1: USD-SOCKETSMD; MICRO-SD-SOCKET-PP
U8: OPA344; SOT23-5
U9: ADMP401

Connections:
+3V3: C13.2, LDR.2, PB1.2, PB2.2, R7.1, U1.4 (VCC), U8.5 (V+), U9.5 (VDD); also elsewhere on the board
BUZZ+: BUZZ.+; also elsewhere on the board
BUZZ-: BUZZ.-; also elsewhere on the board
GND: C5.2, C13.1, R6.2, R12.2, R14.1, R15.1, U1.6 (GND), U1.GND1 (SHIELD1), U1.GND2 (SHIELD2), U8.2 (V-), U9.2 (GND), U9.4 (GND), U9.6 (GND); also elsewhere on the board
LDR: LDR.1, R12.1; also elsewhere on the board
MIC: C4.1, R5.1, U8.1 (OUT); also elsewhere on the board
MISO: U1.7 (DO); also elsewhere on the board
MOSI: U1.3 (DI); also elsewhere on the board
unnamed: C3.2, U9.1 (OUT)
unnamed: C3.1, R4.2
unnamed: C4.2, R4.1, R5.2, U8.4 (-IN)
unnamed: C5.1, R6.1, R7.2, U8.3 (+IN)
PB1: PB1.1, R14.2; also elsewhere on the board
PB2: PB2.1, R15.2; also elsewhere on the board
SCK: U1.5 (SCK); also elsewhere on the board
SD_CD: U1.CD; also elsewhere on the board
SD_CS: U1.2 (CS); also elsewhere on the board

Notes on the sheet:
Micro SD
Push Buttons
Light (LDR)
Buzzer
Noise (Mic)
V2.1.1

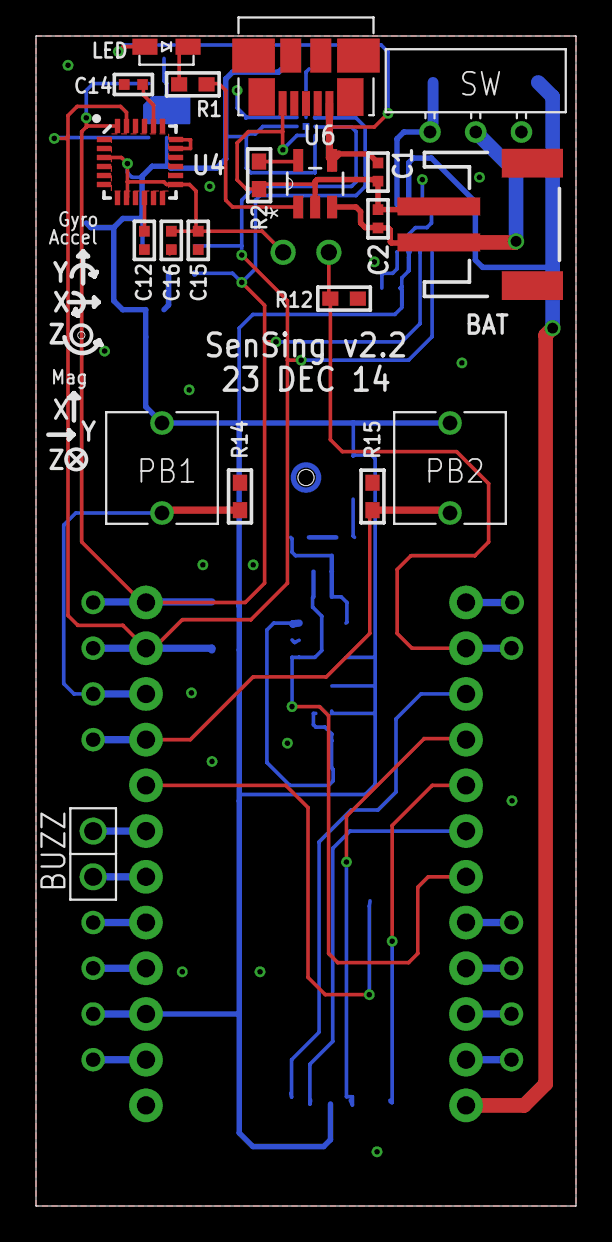
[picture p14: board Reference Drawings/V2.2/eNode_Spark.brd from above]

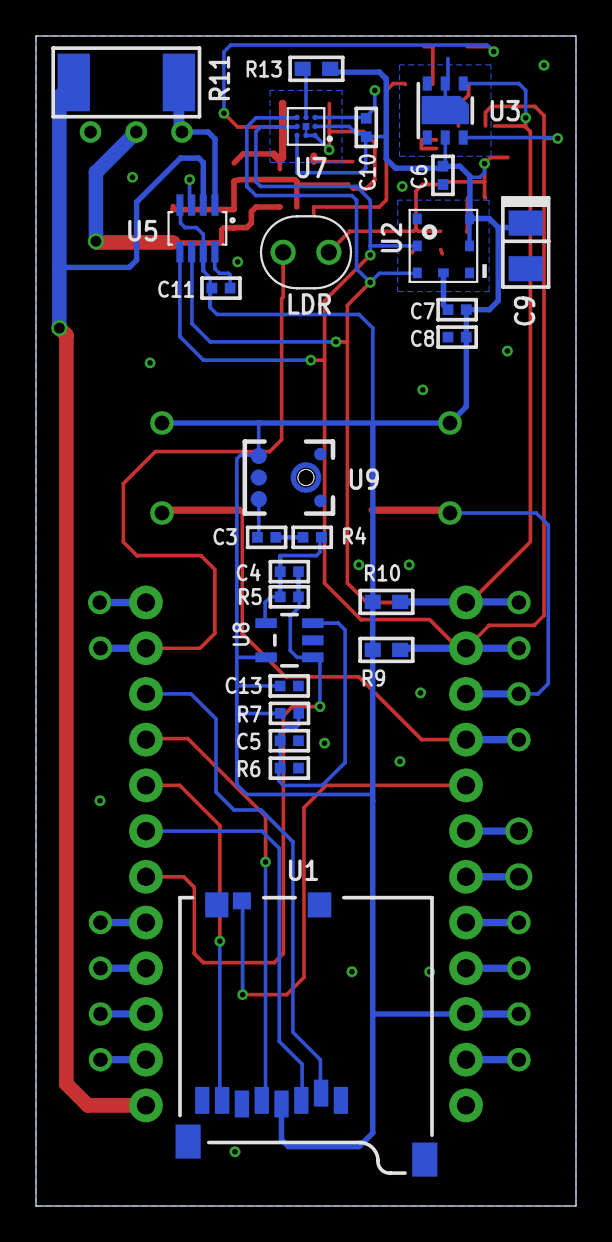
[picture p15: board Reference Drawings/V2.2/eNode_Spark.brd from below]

Board: 2 copper layers, 30.0 x 65.0 mm, 61 parts (26 on the bottom side), 35 nets.

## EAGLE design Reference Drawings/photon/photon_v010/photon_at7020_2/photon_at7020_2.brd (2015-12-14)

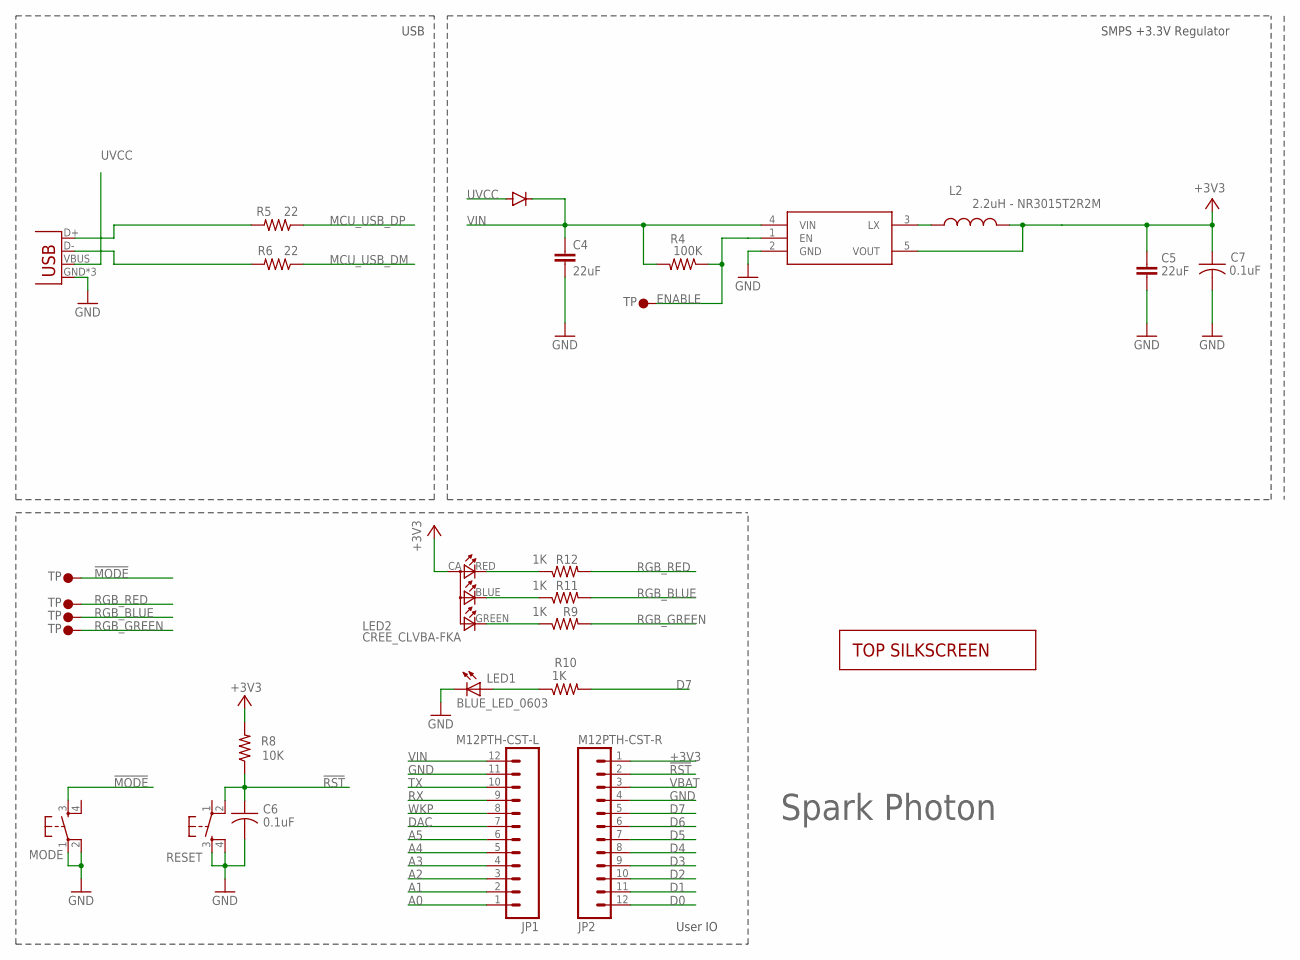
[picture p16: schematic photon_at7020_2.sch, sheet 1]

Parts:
BLUE_LED_0603: LED0603; LED-0603
C4, C5: 22uF; C0603
C6: 0.1uF; C0402_B
C7: 0.1uF; C0402
D1: DIODE; DIODE-DO-220AA(SMP)
JP1: M12PTH-CST-L; 1X12-CASTELLATED
JP2: M12PTH-CST-R; 1X12-CASTELLATED
L2: 2.2uH - NR3015T2R2M; INDUCTOR-NR3015
LED2: CREE_CLVBA-FKA; PLCC4-2MM-RGB
MODE: KMR211GLFS; TACTILE_SWITCH_SMD
R4: 100K; R0402_B
R5, R6: 22; R0402_B
R8: 10K; R0402_B
R9, R10, R11, R12: 1K; R0402_B
RESET: KMR211GLFS; TACTILE_SWITCH_SMD
U$1: PHOTON-TOP-SS
U$3, U$5, U$6, U$7, U$12: TP1; TP35_BOT
U$11: R8008-33; SOT23-5
X1: USB-MICROB; USB-MICROB-SLOT-HOLE

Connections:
!MODE: MODE.3, U$3.P$1; also elsewhere on the board
!RST: C6.1, JP2.2, R8.1, RESET.2; also elsewhere on the board
+3V3: C5.1, C7.1, JP2.1, L2.2, LED2.CA (A2), R8.2, U$11.5 (VOUT); also elsewhere on the board
A0: JP1.1 (12); also elsewhere on the board
A1: JP1.2 (11); also elsewhere on the board
A2: JP1.3 (10); also elsewhere on the board
A3: JP1.4 (9); also elsewhere on the board
A4: JP1.5 (8); also elsewhere on the board
A5: JP1.6 (7); also elsewhere on the board
D0: JP2.12; also elsewhere on the board
D1: JP2.11; also elsewhere on the board
D2: JP2.10; also elsewhere on the board
D3: JP2.9; also elsewhere on the board
D4: JP2.8; also elsewhere on the board
D5: JP2.7; also elsewhere on the board
D6: JP2.6; also elsewhere on the board
D7: JP2.5, R10.2; also elsewhere on the board
DAC: JP1.7 (6); also elsewhere on the board
ENABLE: R4.1, U$11.1 (EN), U$12.P$1
GND: BLUE_LED_0603.C, C4.2, C5.2, C6.2, C7.2, JP1.11 (2), JP2.4, MODE.1, MODE.2, RESET.3, RESET.4, U$11.2 (GND), X1.GND, X1.MT1 (GND), X1.MT2 (GND); also elsewhere on the board
LED1: BLUE_LED_0603.A, R10.1
MCU_USB_DM: R6.1; also elsewhere on the board
MCU_USB_DP: R5.1; also elsewhere on the board
unnamed: R5.2, X1.D+
unnamed: L2.1, U$11.3 (LX)
unnamed: R6.2, X1.D-
unnamed: LED2.BLUE (CBLUE), R11.1
unnamed: LED2.GREEN (CGREEN), R9.1
unnamed: LED2.RED (CRED), R12.1
RGB_BLUE: R11.2, U$6.P$1; also elsewhere on the board
RGB_GREEN: R9.2, U$7.P$1; also elsewhere on the board
RGB_RED: R12.2, U$5.P$1; also elsewhere on the board
RX: JP1.9 (4); also elsewhere on the board
TX: JP1.10 (3); also elsewhere on the board
UVCC: D1.ANODE, X1.VBUS
VBAT: JP2.3; also elsewhere on the board
VIN: C4.1, D1.CATHODE, JP1.12 (1), R4.2, U$11.4 (VIN)
WKP: JP1.8 (5); also elsewhere on the board

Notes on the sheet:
SMPS +3.3V Regulator
User IO
USB
Spark Photon


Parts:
ANT1: AT7020
C2, C3: 100pF; C0402_B
C8, C10, C12, C16: 0.1uF; C0402_B
C9, C11, C13, C15: 10uF; C0402_B
C14: 0.8pF +/-0.25pF (RF); C0402_B
L1: 3.3nH (RF); L0402_B
U1: WM-N-BM-09
U3: RF_SWITCHSC-70-6; SC70-6
U$2: SPARK_LOGO2
U$8, U$9, U$10: TP1; TP35_BOT
X2: IPEX-20279-001E

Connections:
!MODE: U1.53 (GPIO_9/PC7); also elsewhere on the board
!RST: U1.26 (!MCU_RST); also elsewhere on the board
+3V3: C8.2, C9.2, C10.2, C11.1, C12.2, C13.1, U1.19 (VDD_WIFI), U1.20 (VDD_WIFI), U1.46 (VDD_3V3), U1.47 (VDD_3V3), U1.49 (VDDIO_WIFI); also elsewhere on the board
A0: U1.54 (GPIO_8/PC5); also elsewhere on the board
A1: U1.1 (GPIO_7/PC3); also elsewhere on the board
A2: U1.2 (GPIO_6/PC2); also elsewhere on the board
A3: U1.24 (SPI_SCK/PA5); also elsewhere on the board
A4: U1.25 (SPI_MISO/PA6); also elsewhere on the board
A5: U1.23 (SPI_MOSI/PA7); also elsewhere on the board
ANT: U1.15 (ANT), U3.5 (RFC)
BTCX_RF_ACTIVE: U1.9 (BTCX_RF_ACTIVE), U$10.P$1
BTCX_STATUS: U1.10 (BTCX_STATUS), U$9.P$1
BTCX_TXCONF: U1.11 (BTCX_TXCONF), U$8.P$1
CHIP_ANT: L1.1, U3.3 (RF2)
D0: U1.4 (GPIO_4/PB7); also elsewhere on the board
D1: U1.5 (GPIO_3/PB6); also elsewhere on the board
D2: U1.3 (GPIO_5/PB5); also elsewhere on the board
D3: U1.42 (!JTAG_TRST!/PB4); also elsewhere on the board
D4: U1.41 (JTAG_TDO/PB3); also elsewhere on the board
D5: U1.43 (JTAG_TDI/PA15); also elsewhere on the board
D6: U1.40 (JTAG_TCK/PA14); also elsewhere on the board
D7: U1.44 (JTAG_TMS/PA13); also elsewhere on the board
DAC: U1.22 (!SPI_SS!/PA4); also elsewhere on the board
GND: C2.2, C3.2, C8.1, C9.1, C10.1, C11.2, C12.1, C13.2, C14.2, C15.2, C16.2, U1.14 (GND), U1.16 (GND), U1.17 (GND), U1.18 (GND), U1.21 (GND), U1.29 (GND), U1.30 (GND), U1.37 (GND), U1.45 (GND), U1.48 (GND), U1.50 (GND), U1.55 (GND), U1.56 (GND), U1.57 (GND), U1.58 (GND), U1.59 (GND), U1.60 (GND), U1.61 (GND), U1.62 (GND), U1.63 (GND), U1.64 (GND), U1.65 (GND), U1.66 (GND), U1.67 (GND), U3.2 (GND), X2.2@1 (GND), X2.2@2 (GND); also elsewhere on the board
MCU_USB_DM: U1.52 (MCU_USB_DM/PB14); also elsewhere on the board
MCU_USB_DP: U1.51 (MCU_USB_DP/PB15); also elsewhere on the board
unnamed: ANT1.1, C14.1, L1.2
RF_SW_CTRL0_ANT0: C2.1, U1.13 (RF_SW_CTRL0_ANT0), U3.6 (V1)
RF_SW_CTRL3_ANT1: C3.1, U1.12 (RF_SW_CTRL3_ANT1), U3.4 (V2)
RGB_BLUE: U1.6 (GPIO_2/PA3); also elsewhere on the board
RGB_GREEN: U1.7 (GPIO_1/PA2); also elsewhere on the board
RGB_RED: U1.8 (GPIO_0/PA1); also elsewhere on the board
RX: U1.38 (MCU_UART_RX/PA10); also elsewhere on the board
TX: U1.39 (MCU_UART_TX/PA9); also elsewhere on the board
UFL_ANT: U3.1 (RF1), X2.1
VBAT: C15.1, C16.1, U1.28 (VBAT); also elsewhere on the board
WKP: U1.27 (MCU_WKUP); also elsewhere on the board

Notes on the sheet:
Original Arduino Mini Design by Team Arduino
Arduino Pro Mini Design by Spark Fun Electronics
Pro Micro Design by Spark Fun Electronics
Spark Photon design by Spark Labs, Inc. dba Spark IO
Spark Photon
Wi-Fi Module
Spark Logo



Board: 4 copper layers, 20.3 x 35.6 mm, 48 parts (5 on the bottom side), 47 nets.

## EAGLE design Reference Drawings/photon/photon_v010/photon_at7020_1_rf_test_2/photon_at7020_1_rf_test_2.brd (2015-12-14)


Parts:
ANT1: AT7020
C1, C14: 0.8pF +/-0.25pF (RF); C0402_B
L1: 3.3nH (RF); L0402_B
M2X5-CASTELLATED: M2X5; 2X5-CASTELLATED
X1: SMACONNECTOR_EDGE; SMA_EDGELAUNCH

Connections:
CHIP_ANT: C1.1, L1.1, X1.P (ANT)
GND: C1.2, C14.2, X1.GND@1 (GND4), X1.GND@2 (GND3), X1.GND@3 (GND2), X1.GND@4 (GND1)
unnamed: ANT1.1, C14.1, L1.2
RF_SW_CTRL0_ANT0: M2X5-CASTELLATED.1
RF_SW_CTRL3_ANT1: M2X5-CASTELLATED.10

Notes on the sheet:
Spark Photon design by Spark Labs, Inc. dba Spark IO
RF Test Board #1-2
RF Test Board


Board: 4 copper layers, 20.3 x 15.2 mm, 6 parts (0 on the bottom side), 3 nets.

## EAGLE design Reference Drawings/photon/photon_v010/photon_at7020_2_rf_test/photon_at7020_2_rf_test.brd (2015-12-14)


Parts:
ANT1: AT7020
C2, C3: 100pF; C0402_B
C12, C16: 0.1uF; C0402_B
C13, C15: 10uF; C0402_B
C14: 0.8pF +/-0.25pF (RF); C0402_B
L1: 3.3nH (RF); L0402_B
M2X5-CASTELLATED: M2X5; 2X5-CASTELLATED
U3: RF_SWITCHSC-70-6; SC70-6
X1: SMACONNECTOR_EDGE; SMA_EDGELAUNCH
X2: IPEX-20279-001E

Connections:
+3V3: C12.2, C13.1
ANT: U3.5 (RFC), X1.P (ANT)
CHIP_ANT: L1.1, U3.3 (RF2)
GND: C2.2, C3.2, C12.1, C13.2, C14.2, C15.2, C16.2, U3.2 (GND), X1.GND@1 (GND4), X1.GND@2 (GND3), X1.GND@3 (GND2), X1.GND@4 (GND1), X2.2@1 (GND), X2.2@2 (GND)
unnamed: ANT1.1, C14.1, L1.2
RF_SW_CTRL0_ANT0: C2.1, M2X5-CASTELLATED.1, U3.6 (V1)
RF_SW_CTRL3_ANT1: C3.1, M2X5-CASTELLATED.10, U3.4 (V2)
UFL_ANT: U3.1 (RF1), X2.1
VBAT: C15.1, C16.1

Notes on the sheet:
Spark Photon RF Test Board design by Spark Labs, Inc. dba Spark IO
RF Test Board #2
RF Test Board
RF_SW_CTRL0_ANT0
RF_SW_CTRL3_ANT1
+3.3V
CHIP ANT
u.FL ANT


Board: 4 copper layers, 20.3 x 15.2 mm, 13 parts (0 on the bottom side), 9 nets.

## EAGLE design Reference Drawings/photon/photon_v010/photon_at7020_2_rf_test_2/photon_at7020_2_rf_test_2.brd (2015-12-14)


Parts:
ANT1: AT7020
C14: 0.8pF +/-0.25pF (RF); C0402_B
L1: 3.3nH (RF); L0402_B
M2X5-CASTELLATED: M2X5; 2X5-CASTELLATED
X1: SMACONNECTOR_EDGE; SMA_EDGELAUNCH

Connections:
CHIP_ANT: L1.1, X1.P (ANT)
GND: C14.2, X1.GND@1 (GND4), X1.GND@2 (GND3), X1.GND@3 (GND2), X1.GND@4 (GND1)
unnamed: ANT1.1, C14.1, L1.2
RF_SW_CTRL0_ANT0: M2X5-CASTELLATED.1
RF_SW_CTRL3_ANT1: M2X5-CASTELLATED.10

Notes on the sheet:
Spark Photon RF Test Board design by Spark Labs, Inc. dba Spark IO
RF Test Board #2-2
RF Test Board


Board: 4 copper layers, 20.3 x 15.2 mm, 5 parts (0 on the bottom side), 3 nets.

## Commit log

2015-12-14 better design
    [V3.5 BOM 20151209.xlsx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]
2016-01-04 Changed to Micro USB B.lbr
    [V3.5 BOM 20151209.xlsx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]

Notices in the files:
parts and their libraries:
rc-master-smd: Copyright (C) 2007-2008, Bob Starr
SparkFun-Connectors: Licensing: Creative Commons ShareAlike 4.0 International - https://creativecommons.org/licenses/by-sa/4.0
